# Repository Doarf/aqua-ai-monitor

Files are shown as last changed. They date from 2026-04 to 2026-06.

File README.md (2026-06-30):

# aqua-ai-monitor

<div align="center">

aqua-ai-monitor logo

**Automated monitoring system for aquaculture basins**  
*IoT · Isolation Forest AI · MJPEG Video · Node.js · Flask · Chart.js*













</div>

---

## About the project

**aqua-ai-monitor** is a fully autonomous embedded platform for real-time aquaculture basin monitoring. It combines physicochemical sensor acquisition, live underwater video streaming, automatic CSV logging, and an on-the-fly trainable **Isolation Forest** anomaly detection model — all accessible from a web dashboard, with optional remote access via ngrok.

### The problem

Aquaculture basins require constant monitoring. A pH shift, rising turbidity or abnormal water conditions can cause significant losses within hours. Manual monitoring is expensive, discontinuous and reactive — the need is to be **proactive**.

### The solution

| Need | Solution |
|---|---|
| Continuous acquisition | ESP32 reads 5 sensors every 2 s |
| Wi-Fi transmission | HTTP/JSON POST to Node.js server |
| Data history | Automatic CSV logging on PC |
| Anomaly detection | Isolation Forest (Python/Flask microservice) |
| Real-time visualization | Web dashboard with live charts (Chart.js) |
| Live video | ESP32-CAM + OV2640 → MJPEG stream |
| Remote access | ngrok HTTPS tunnel |

---

## Architecture

```
Physical sensors          OV2640 camera
      │                        │
      ▼ OneWire/ADC/I²C        ▼ MIPI CSI
  ESP32 Aqua              ESP32-CAM
      │                        │
      └──── Wi-Fi HTTP ─────────┘
                  │
                  ▼
        PC — Node.js (:3000) ◄──► Flask AI (:5001)
                  │                    │
                  │ ◄── /predict ───────┘
                  │
            data_aqua.csv  (auto-logged)
                  │
                  ▼
          Web Dashboard (:3000)
                  │
                  ▼ (optional)
          ngrok HTTPS tunnel
```

---

## Hardware components

| Component | Reference | Interface | Measured parameter |
|---|---|---|---|
| Main microcontroller | ESP32-WROOM-32 | Wi-Fi, GPIO | Acquisition & transmission |
| Camera microcontroller | ESP32-CAM | Wi-Fi, MIPI CSI | Underwater video |
| Water temperature | DS18B20 | OneWire (GPIO 4) | Water temp (°C) |
| Air temp & humidity | DHT22 | Single-wire (GPIO 15) | Air temp (°C), humidity (%) |
| pH sensor | PH-4502C | ADC (GPIO 34) | pH (0–14) |
| Turbidity sensor | Keyestudio V1.0 | ADC (GPIO 35) | Turbidity (NTU) |
| Camera | OV2640 | MIPI CSI | JPEG VGA video |
| OLED display | SSD1306 128×64 | I²C (GPIO 21/22) | Local readout |

---

## Software stack

| Layer | Technology | Role |
|---|---|---|
| Firmware | C++ / PlatformIO | Sensor reading, HTTP send |
| Server | Node.js / Express | Data relay, CSV logging, MJPEG proxy |
| AI service | Python / Flask | Isolation Forest training & inference |
| Dashboard | HTML/JS + Chart.js | Real-time charts, alerts, CSV upload |
| Remote access | ngrok | HTTPS tunnel |

---

## AI — Anomaly detection

The AI module uses an **Isolation Forest** model, trained on normal basin data collected by the system itself.

- **Unsupervised** — no labelled data required
- **Inputs** — pH and turbidity (NTU)
- **Double logic** — business rule thresholds + statistical IF score
- **Score** — normalized 0 (normal) → 1 (highly anomalous)
- **Trainable on the fly** — upload a CSV from the dashboard, click *Train*

```python
model = IsolationForest(n_estimators=200, contamination=0.05, random_state=42)
```

---

## Getting started

### Prerequisites

- Node.js ≥ 18
- Python ≥ 3.11
- PlatformIO
- ngrok (optional, for remote access)

### Launch the server & AI service

```bash
# Terminal 1 — Python AI microservice
cd esp32_cam_stream
pip install flask flask-cors scikit-learn pandas numpy joblib
python ai_service.py          # → http://localhost:5001

# Terminal 2 — Node.js server
cd esp32_cam_stream
npm install
node server.js                # → http://localhost:3000

# Terminal 3 — Remote access (optional)
ngrok http 3000
```

### Flash the ESP32 firmware

```bash
cd esp32_code/esp32_aqua
# Copy src/config_secret.h.example → src/config_secret.h
# Fill in your WIFI_SSID, WIFI_PASSWORD, SERVER_URL
pio run --target upload
pio device monitor --baud 115200
```

### Flash the ESP32-CAM

```bash
cd esp32_cam
# Copy src/config_secret.h.example → src/config_secret.h
# Fill in your WIFI_SSID and WIFI_PASSWORD
pio run --target upload
```

### Train the AI model

1. Let the system run for ~30 min under normal conditions
2. Open `http://localhost:3000`
3. Click **Download CSV** to get `data_aqua.csv`
4. Drag & drop the CSV into the AI panel → click **Train**
5. Model is active in under 1 second

---

## Repository structure

```
aqua-ai-monitor/
├── esp32_code/
│   └── esp32_aqua/              # Sensor firmware (PlatformIO)
│       └── src/
│           ├── main.cpp
│           ├── config.h
│           ├── config_secret.h.example
│           ├── ph_sensor.cpp/h
│           ├── turbidity_sensor.cpp/h
│           ├── ds18b20_sensor.cpp/h
│           ├── dht_sensor.cpp/h
│           ├── screen_oled.cpp/h
│           └── http_sender.cpp/h
├── esp32_cam/                   # Camera firmware (PlatformIO)
│   └── src/
│       ├── main.cpp
│       ├── camera.cpp/h
│       ├── streamer.cpp/h
│       ├── config.h
│       └── config_secret.h.example
├── esp32_cam_stream/            # Server + AI + Dashboard
│   ├── server.js                # Node.js/Express server
│   ├── ai_service.py            # Flask AI microservice
│   └── public/
│       └── index.html           # Web dashboard
├── SEBB_aqua/
│   └── carte_aqua/              # KiCad PCB project + Gerbers
├── docs/
│   └── banner.svg
├── rapport_aqua_ai_monitor.tex
└── rapport_aqua_ai_monitor.pdf
```

---

<div align="center">
  <sub>SPI Project · aqua-ai-monitor · IoT & AI for aquaculture</sub>
</div>

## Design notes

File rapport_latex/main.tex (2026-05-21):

% ============================================================
%  RAPPORT DE PROJET — aqua-ai-monitor
%  Plateforme Intelligente de Suivi en Aquaculture
%  CESI Nanterre — Programme FISA — SPI
% ============================================================
\documentclass[12pt,a4paper]{report}

% ── Encodage & langue ────────────────────────────────────────
\usepackage[utf8]{inputenc}
\usepackage[T1]{fontenc}
\usepackage[french]{babel}

% ── Mise en page ─────────────────────────────────────────────
\usepackage[top=2.5cm,bottom=2.5cm,left=2.8cm,right=2.8cm]{geometry}
\usepackage{setspace}
\onehalfspacing

% ── Typographie ──────────────────────────────────────────────
\usepackage{courier}
\usepackage[protrusion=false,expansion=false]{microtype}
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
\usepackage{fancyhdr}
\setlength{\headheight}{13.6pt}
\pagestyle{fancy}
\fancyhf{}
\fancyhead[L]{\small\textcolor{secondary}{aqua-ai-monitor}}
\fancyhead[R]{\small\textcolor{secondary}{\leftmark}}
\fancyfoot[C]{\small\textcolor{secondary}{\thepage}}
\renewcommand{\headrulewidth}{0.4pt}
\renewcommand{\footrulewidth}{0pt}

% ── Titres de chapitres personnalisés ────────────────────────
\usepackage{titlesec}
\titleformat{\chapter}[display]
  {\normalfont\huge\bfseries\color{primary}}
  {\chaptertitlename\ \thechapter}{12pt}{\Huge}
\titlespacing*{\chapter}{0pt}{-20pt}{30pt}

\titleformat{\section}
  {\normalfont\Large\bfseries\color{primary}}{\thesection}{1em}{}
\titleformat{\subsection}
  {\normalfont\large\bfseries\color{secondary}}{\thesubsection}{1em}{}
\titleformat{\subsubsection}
  {\normalfont\normalsize\bfseries\color{secondary}}{\thesubsubsection}{1em}{}

% ── Tableaux ─────────────────────────────────────────────────
\usepackage{booktabs}
\makeatletter
\def\CT@arc@{\relax}
\makeatother
\usepackage{tabularx}
\usepackage{multirow}
\usepackage{array}
\usepackage{longtable}
\newcolumntype{L}[1]{>{\raggedright\arraybackslash}p{#1}}
\newcolumntype{C}[1]{>{\centering\arraybackslash}p{#1}}
\newcolumntype{R}[1]{>{\raggedleft\arraybackslash}p{#1}}

% ── Listes ───────────────────────────────────────────────────
\usepackage{enumitem}
\setlist[itemize]{noitemsep, topsep=4pt}
\setlist[enumerate]{noitemsep, topsep=4pt}

% ── Code source ──────────────────────────────────────────────
\usepackage{listings}
\usepackage{lstautogobble}

\lstdefinestyle{mystyle}{
  backgroundcolor=\color{codebg},
  basicstyle=\ttfamily\footnotesize,
  breakatwhitespace=false,
  breaklines=true,
  captionpos=b,
  commentstyle=\color{accent}\itshape,
  keywordstyle=\color{primary}\bfseries,
  stringstyle=\color{warning},
  numbers=left,
  numberstyle=\tiny\color{secondary},
  numbersep=8pt,
  showstringspaces=false,
  tabsize=2,
  frame=single,
  framesep=4pt,
  rulecolor=\color{secondary!30},
  autogobble=true,
  xleftmargin=14pt,
}
\lstset{style=mystyle}

\lstdefinelanguage{JavaScript}{
  keywords={const,let,var,function,return,if,else,try,catch,async,await,new,require,module,exports,true,false,null},
  morestring=[b]',
  morestring=[b]",
  morecomment=[l]{//},
  morecomment=[s]{/*}{*/},
  sensitive=true
}

\lstdefinelanguage{Python3}{
  keywords={def,class,return,if,elif,else,for,while,import,from,try,except,with,as,True,False,None,and,or,not,in,is,lambda,global},
  morestring=[b]',
  morestring=[b]",
  morecomment=[l]{\#},
  sensitive=true
}

% ── Boîtes d'information ─────────────────────────────────────
\usepackage{tcolorbox}
\tcbuselibrary{breakable,skins}

\newtcolorbox{infobox}[1][]{
  colback=primary!5, colframe=primary!60,
  fonttitle=\bfseries, title=#1,
  breakable, boxrule=0.5pt, arc=3pt
}

\newtcolorbox{warningbox}[1][]{
  colback=warning!8, colframe=warning!60,
  fonttitle=\bfseries, title=#1,
  breakable, boxrule=0.5pt, arc=3pt
}

\newtcolorbox{successbox}[1][]{
  colback=accent!8, colframe=accent!60,
  fonttitle=\bfseries, title=#1,
  breakable, boxrule=0.5pt, arc=3pt
}

% ── Liens hypertextes ────────────────────────────────────────
\usepackage[hidelinks,colorlinks=true,linkcolor=primary,urlcolor=primary,citecolor=primary]{hyperref}

% ── Divers ───────────────────────────────────────────────────
\usepackage{float}
\usepackage{caption}
\captionsetup{font=small,labelfont=bf,labelsep=period}
\usepackage{subcaption}
\usepackage{amsmath}
\usepackage{amssymb}
\usepackage{pifont}
\newcommand{\cmark}{\textcolor{accent}{\ding{51}}}
\newcommand{\xmark}{\textcolor{danger}{\ding{55}}}

% ── Commandes personnalisées ─────────────────────────────────
\newcommand{\code}[1]{\texttt{\small\colorbox{codebg}{#1}}}
\newcommand{\param}[2]{\code{#1} & \small #2 \\}

% ============================================================
%  DÉBUT DU DOCUMENT
% ============================================================
\begin{document}

% ── Page de titre ────────────────────────────────────────────
\begin{titlepage}
  \centering
  \vspace*{1cm}

  \begin{tikzpicture}
    \node[circle,fill=primary,minimum size=3cm] (logo) {
      \textcolor{white}{\fontsize{40}{40}\selectfont\textbf{A}}
    };
  \end{tikzpicture}

  \vspace{0.8cm}
  {\fontsize{28}{32}\selectfont\bfseries\color{primary} aqua-ai-monitor}

  \vspace{0.4cm}
  {\Large\color{secondary} Plateforme Intelligente de Suivi en Aquaculture}

  \vspace{0.8cm}
  \textcolor{secondary!60}{\rule{0.6\textwidth}{0.4pt}}

  \vspace{0.8cm}
  {\large Rapport de Projet --- Systèmes et Projets Industriels}

  \vspace{1cm}
  \begin{tabular}{ll}
    \textbf{Établissement} & CESI Nanterre \\[4pt]
    \textbf{Programme}     & FISA --- Ingénierie des Systèmes Embarqués \\[4pt]
    \textbf{Promotion}     & 2024--2027 \\[4pt]
    \textbf{Encadrant}     & Kamel AIZI \\[4pt]
  \end{tabular}

  \vspace{1cm}
  \textcolor{secondary!60}{\rule{0.6\textwidth}{0.4pt}}

  \vspace{0.8cm}
  \textbf{Équipe projet}

  \vspace{0.4cm}
  \begin{tabular}{ll}
    DOGOTARU Arthur   & Chef de projet --- GUI, IA \\[4pt]
    LEGALL Maxence    & Capteurs, traitement de données \\[4pt]
    HAMMOUDA Nouhaila & PCB, schématique électronique \\[4pt]
  \end{tabular}

  \vspace{0.6cm}
  \textcolor{secondary!60}{\rule{0.6\textwidth}{0.4pt}}

  \vspace{0.4cm}
  {\small\color{secondary} Code source disponible sur GitHub :}\\[4pt]
  \href{https://github.com/Doarf/aqua_ai_monitor}{%
    \texttt{\color{primary}https://github.com/Doarf/aqua\_ai\_monitor}}

  \vfill
  {\color{secondary}\today}
\end{titlepage}

% ── Résumé ──────────────────────────────────────────────────
\chapter*{Résumé}
\addcontentsline{toc}{chapter}{Résumé}
\thispagestyle{fancy}

Le secteur de l'aquaculture est confronté à des défis croissants en matière de surveillance continue
des conditions d'élevage. Les variations de paramètres physicochimiques tels que le pH ou la turbidité
de l'eau peuvent provoquer des pertes importantes en quelques heures, sans que l'opérateur soit
nécessairement présent pour les détecter.

Le projet \textbf{aqua-ai-monitor} propose une réponse à cette problématique en développant une
plateforme embarquée autonome, combinant acquisition de données IoT, traitement temps réel et
intelligence artificielle. Le système repose sur deux microcontrôleurs ESP32 --- l'un dédié à l'acquisition
sensorielle (température, pH, turbidité, humidité), l'autre à la capture vidéo par caméra OV2640 ---
qui transmettent leurs données par Wi-Fi à un serveur central.

Ce serveur, développé en Node.js, agrège les flux de données, les enregistre dans un fichier CSV,
et les transmet à un microservice Python hébergeant un modèle \textit{Isolation Forest} entraînable
à la volée. La détection d'anomalies repose sur une double logique : seuils métier configurables
et score d'anomalie statistique. Les résultats sont présentés via un tableau de bord web en temps réel,
incluant graphiques d'évolution temporelle, alertes colorées et module d'entraînement par upload CSV.
L'accès distant est assuré via un tunnel ngrok sans configuration réseau spécifique.

\vspace{0.5cm}
\textbf{Mots-clés :} ESP32, IoT, aquaculture, détection d'anomalies, Isolation Forest,
Node.js, Flask, Chart.js, KiCad, PlatformIO, ngrok.

\clearpage

% ── Table des matières ───────────────────────────────────────
\tableofcontents
\clearpage

% ── Liste des figures ────────────────────────────────────────
\listoffigures
\addcontentsline{toc}{chapter}{Liste des figures}
\clearpage

% ── Liste des tableaux ───────────────────────────────────────
\listoftables
\addcontentsline{toc}{chapter}{Liste des tableaux}
\clearpage

% ============================================================
%  CHAPITRE 1 — INTRODUCTION ET CONTEXTE
% ============================================================
\chapter{Introduction et contexte}

\section{Présentation du projet}

Le projet \textbf{aqua-ai-monitor} est un système de surveillance automatisée de bassins
aquacoles développé dans le cadre du projet de Systèmes et Projets Industriels (SPI) de
deuxième année FISA au CESI Nanterre. Il vise à concevoir une plateforme complète, de la
couche matérielle embarquée jusqu'à l'interface utilisateur et l'intelligence artificielle,
répondant à une problématique industrielle réelle.

L'équipe est composée de trois étudiants aux compétences complémentaires :
\begin{itemize}
  \item \textbf{Arthur Dogotaru} --- Chef de projet, responsable de l'interface graphique (GUI),
        du microservice d'intelligence artificielle et de l'intégration logicielle globale ;
  \item \textbf{Legall Maxence} --- Responsable de l'intégration des capteurs et du traitement
        des données embarquées ;
  \item \textbf{Hammouda Nouhaila} --- Responsable de la conception PCB et des schématiques
        électroniques sous KiCad.
\end{itemize}

\section{Problématique industrielle}

L'aquaculture représente une part croissante de la production mondiale de protéines animales.
Selon la FAO~\cite{fao_aquaculture}, elle couvre aujourd'hui plus de 50\,\% de la consommation
mondiale de poissons. La gestion des bassins d'élevage constitue cependant un défi opérationnel
majeur : les organismes aquatiques sont extrêmement sensibles aux variations de leur environnement.

\begin{warningbox}[Risques liés à la surveillance manuelle]
Un écart de pH de 0,5 unité peut entraîner un stress physiologique significatif chez les
poissons. Une turbidité excessive indique une prolifération bactérienne ou une contamination.
Sans surveillance continue, ces anomalies peuvent provoquer des pertes totales d'un élevage
en moins de 24 heures.
\end{warningbox}

La surveillance manuelle présente trois limitations fondamentales :
\begin{enumerate}
  \item \textbf{Discontinuité} : les relevés manuels sont typiquement effectués une à deux fois
        par jour, laissant de larges fenêtres de non-détection ;
  \item \textbf{Réactivité} : une intervention humaine est nécessaire pour interpréter les mesures
        et déclencher une alerte, introduisant un délai incompressible ;
  \item \textbf{Coût} : la mobilisation permanente de personnel qualifié représente une charge
        opérationnelle élevée pour les petites et moyennes exploitations aquacoles.
\end{enumerate}

\section{Objectifs du projet}

Le projet aqua-ai-monitor vise à répondre à ces trois limitations par un système autonome
capable de :

\begin{itemize}
  \item Collecter en continu les paramètres physicochimiques (pH, turbidité, températures,
        humidité) via des capteurs connectés à un microcontrôleur ESP32 ;
  \item Transmettre ces données par Wi-Fi à un serveur central via le protocole HTTP/JSON ;
  \item Enregistrer les données dans un fichier CSV pour constitution d'un historique ;
  \item Analyser les données à l'aide d'un modèle d'apprentissage automatique non supervisé
        (Isolation Forest) pour détecter les anomalies sans nécessiter de labellisation préalable ;
  \item Présenter les résultats en temps réel sur un tableau de bord web accessible depuis
        n'importe quel navigateur sur le réseau local ;
  \item Permettre un accès distant au tableau de bord via un tunnel sécurisé ngrok,
        sans configuration réseau spécifique ;
  \item Capturer un flux vidéo sous-marin pour l'observation comportementale des poissons.
\end{itemize}

\section{Structure du rapport}

Ce rapport est organisé en dix chapitres. Le \textbf{chapitre~2} présente l'état de l'art
des systèmes IoT de surveillance aquacole et des méthodes de détection d'anomalies. Le
\textbf{chapitre~3} décrit l'architecture générale du système et les choix technologiques.
Le \textbf{chapitre~4} présente le matériel électronique et la carte PCB. Le
\textbf{chapitre~5} détaille les firmwares ESP32. Le \textbf{chapitre~6} présente le serveur
Node.js et l'infrastructure logicielle. Le \textbf{chapitre~7} développe le module
d'intelligence artificielle. Le \textbf{chapitre~8} présente le tableau de bord web. Le
\textbf{chapitre~9} présente les résultats et la validation du système. Le
\textbf{chapitre~10} conclut et ouvre sur les perspectives.

% ============================================================
%  CHAPITRE 2 — ÉTAT DE L'ART
% ============================================================
\chapter{État de l'art}
\label{chap:etat_art}

\section{Surveillance IoT de la qualité de l'eau en aquaculture}

La surveillance continue des paramètres physicochimiques d'un bassin aquacole
par des systèmes embarqués connectés est un axe de recherche actif depuis le milieu
des années 2010. Les travaux récents convergent vers une architecture commune :
des microcontrôleurs à faible consommation équipés de capteurs analogiques ou numériques,
transmettant leurs données via Wi-Fi ou LoRaWAN vers une plateforme de visualisation
et d'analyse.

\subsection{Systèmes ESP32 multi-capteurs pour l'aquaculture}

L'article de référence dans ce domaine est celui de Lin \textit{et al.}
\cite{lin2021aqua}, qui propose un système multi-capteurs intégrant température, pH,
oxygène dissous (DO) et conductivité électrique (EC) sur un module ESP32 Wi-Fi.
Les données sont transmises vers la plateforme ThingSpeak et visualisées via une
application mobile. Les auteurs rapportent une erreur absolue moyenne de
$0{,}0331$~°C sur la température après calibration, validant la pertinence de
l'ESP32 pour ce type d'application. Cette architecture est directement comparable
à celle d'\textbf{aqua-ai-monitor}, avec deux différences principales : notre
système ajoute un capteur de turbidité (NTU) et un module de détection d'anomalies
par apprentissage automatique, absents du travail de Lin \textit{et al.}

\subsection{Capteurs bas coût pour la surveillance IoT de l'eau}

Une revue systématique publiée dans \textit{Sensors} par de~Camargo \textit{et al.}
\cite{camargo2023lowcost} analyse 78~articles portant sur des capteurs bas coût
intégrés à des systèmes IoT de surveillance de la qualité de l'eau.
Les auteurs identifient le pH et la turbidité comme les paramètres les plus
fréquemment mesurés mais aussi les plus sensibles aux dérives de calibration.
Ils soulignent que les capteurs électrochimiques de pH présentent une dérive
temporelle non négligeable et nécessitent une recalibration régulière sur deux
points de référence --- constat que corrobore notre expérience avec le module
PH-4502C (cf.~section~\ref{sec:ph} et tableau~\ref{tab:validation}).
Cette revue justifie notre choix d'intégrer un \code{PH\_OFFSET} ajustable dans
\code{config.h} plutôt qu'une formule fixe.

\subsection{Limites de la surveillance par seuils fixes}

Les travaux de El-Shafeiy \textit{et al.} \cite{elshafeiy2023anomaly} montrent
que la simple vérification de seuils fixes est insuffisante pour détecter les
anomalies dans des séries temporelles de capteurs eau : les auteurs testent
plusieurs approches de détection sur des flux multi-capteurs et concluent que
les méthodes d'apprentissage non supervisé détectent des dégradations progressives
que les seuils manquent systématiquement. Cette observation motive directement
le couplage seuils métier + Isolation Forest retenu dans aqua-ai-monitor.

\section{Détection d'anomalies par apprentissage automatique non supervisé}

\subsection{Isolation Forest appliqué aux réseaux de capteurs IoT}

La détection d'anomalies dans les flux de capteurs IoT par Isolation Forest a été
étudiée dans plusieurs contextes récents. Zhuang \textit{et al.}
\cite{zhuang2023bsiforest} proposent BS-iForest, une variante améliorée de
l'algorithme original de Liu \textit{et al.} \cite{liu2008isolation}, appliquée
aux réseaux de capteurs sans fil. Les auteurs identifient deux limites de
l'Isolation Forest classique : une forte composante aléatoire entre deux
entraînements successifs sur le même jeu de données, et des performances dégradées
sur les données de faible densité. Pour notre application, la faible dimensionnalité
du problème (2~variables : pH et NTU) atténue ce second problème, et la graine
aléatoire fixée (\code{random\_state=42}) assure la reproductibilité de
l'entraînement.

\subsection{Comparaison avec les approches alternatives}

Les autoencodeurs (deep learning) sont régulièrement proposés dans la littérature
\cite{elshafeiy2023anomaly} mais leurs exigences en données d'entraînement
(plusieurs milliers de points) et en ressources de calcul les rendent inadaptés
à un déploiement sur PC local avec une phase de démarrage de quelques dizaines de
minutes. L'Isolation Forest, de complexité linéaire en $O(n \log n)$, peut
s'entraîner en moins d'une seconde sur 100~points, ce qui correspond exactement
à la contrainte opérationnelle du projet. Une comparaison détaillée des algorithmes
est présentée au tableau~\ref{tab:algos} du chapitre~\ref{chap:ia}.

\section{Outils de développement pour systèmes IoT embarqués}

Les systèmes IoT embarqués modernes s'appuient sur des environnements de
développement spécialisés. PlatformIO~\cite{platformio}, associé à l'éditeur
VS Code, s'est imposé comme la référence pour le développement sur
microcontrôleurs ESP32 : il unifie la gestion des bibliothèques, la compilation
et le flashage dans un seul outil, là où l'IDE Arduino classique montrait ses
limites sur des projets multi-fichiers. Lin \textit{et al.}~\cite{lin2021aqua}
utilisent également ce type d'environnement intégré pour leur système
multi-capteurs aquacole.

Côté serveur, Node.js s'est largement imposé pour les applications IoT temps
réel grâce à son modèle événementiel non bloquant, particulièrement adapté à la
gestion de nombreuses connexions simultanées à faible latence. La revue de
de~Camargo \textit{et al.}~\cite{camargo2023lowcost} recense Node.js parmi les
plateformes serveur les plus utilisées dans les architectures IoT de surveillance
environnementale.

Pour le prototypage mécanique, les imprimantes 3D de type \textbf{Bambu Lab}
permettent la fabrication rapide de boîtiers sur mesure adaptés aux contraintes
environnementales (humidité, câblage, fixation). Cette approche réduit le temps
entre prototype logiciel et déploiement physique, tendance recensée dans la
littérature IoT récente.

Enfin, l'accès distant aux dashboards IoT sans infrastructure réseau dédiée
est rendu possible par des outils de tunneling comme \textbf{ngrok}, qui créent
un tunnel HTTPS sécurisé entre un serveur local et internet. Cette approche est
particulièrement adaptée aux petites exploitations ne disposant pas d'adresse IP
fixe ni de configuration réseau avancée.

\begin{figure}[H]
  \centering
  \begin{subfigure}[b]{0.14\textwidth}
    \centering
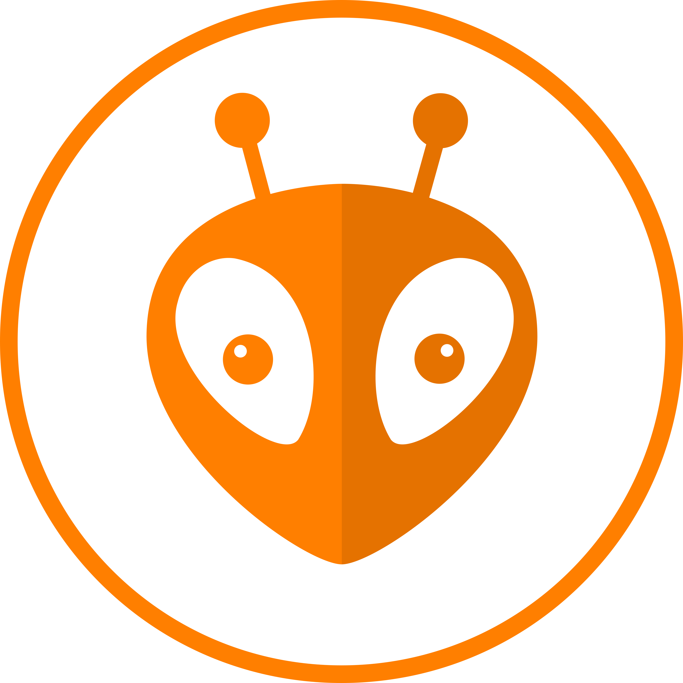
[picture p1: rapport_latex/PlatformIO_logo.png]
    
    \caption{PlatformIO}
  \end{subfigure}
  \hspace{0.5cm}
  \begin{subfigure}[b]{0.14\textwidth}
    \centering
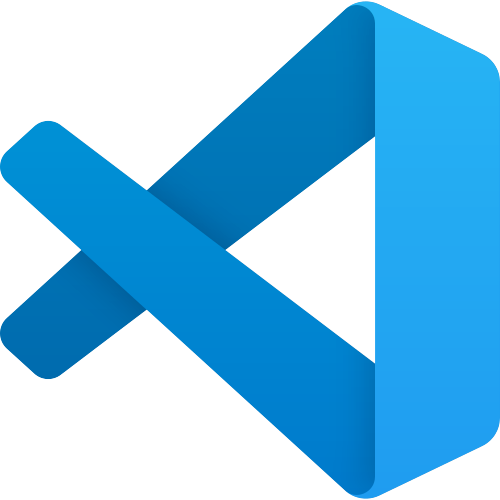
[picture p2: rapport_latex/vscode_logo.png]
    
    \caption{VS Code}
  \end{subfigure}
  \hspace{0.5cm}
  \begin{subfigure}[b]{0.20\textwidth}
    \centering
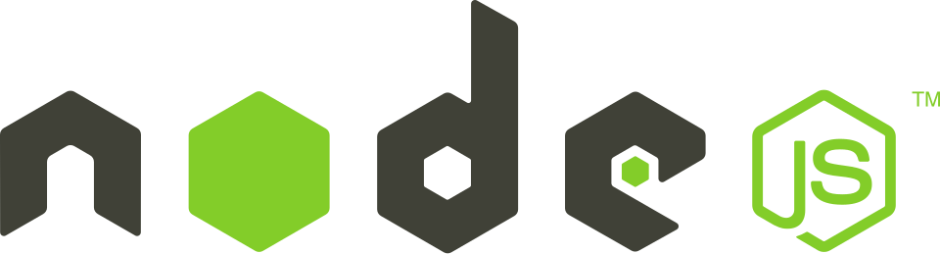
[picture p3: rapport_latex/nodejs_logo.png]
    
    \caption{Node.js}
  \end{subfigure}
  \hspace{0.5cm}
  \begin{subfigure}[b]{0.16\textwidth}
    \centering
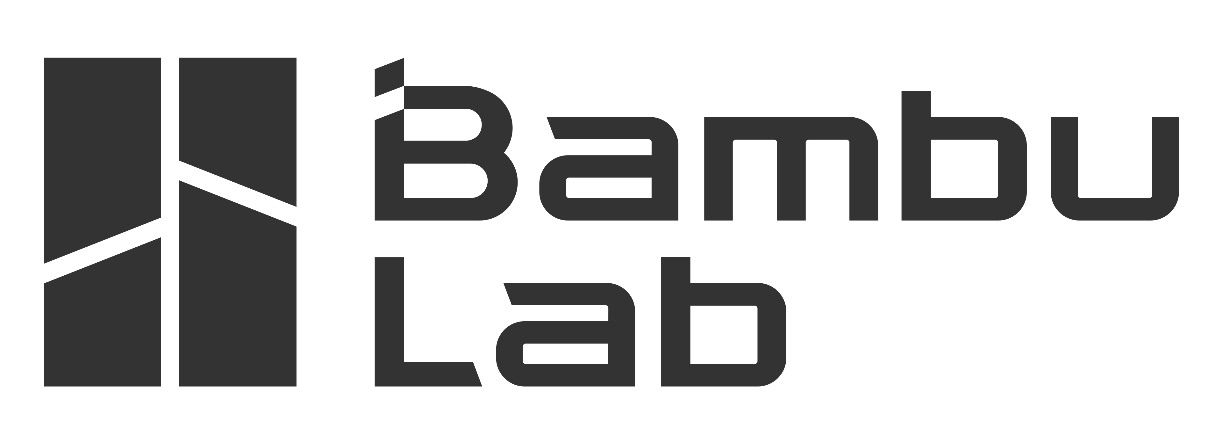
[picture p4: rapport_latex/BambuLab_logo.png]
    
    \caption{Bambu Lab}
  \end{subfigure}
  \hspace{0.5cm}
  \begin{subfigure}[b]{0.16\textwidth}
    \centering
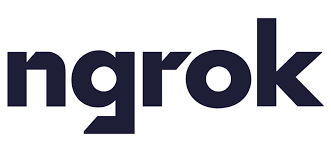
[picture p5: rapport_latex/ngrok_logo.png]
    
    \caption{ngrok}
  \end{subfigure}
  \caption{Outils logiciels et matériels de référence pour le développement IoT embarqué}
  \label{fig:logos_outils}
\end{figure}

\section{Positionnement du projet aqua-ai-monitor}

\begin{table}[H]
\centering
\caption{Positionnement d'aqua-ai-monitor par rapport aux travaux de l'état de l'art}
\label{tab:etat_art}
\begin{tabularx}{\textwidth}{@{}L{4cm}C{2cm}C{2cm}C{2.5cm}C{2.5cm}@{}}
\toprule
\textbf{Système} & \textbf{ESP32} & \textbf{Turbidité} & \textbf{Détection IA} & \textbf{Flux vidéo} \\
\midrule
Lin \textit{et al.}~\cite{lin2021aqua}                & \cmark & \xmark & \xmark        & \xmark \\
El-Shafeiy \textit{et al.}~\cite{elshafeiy2023anomaly} & \xmark & \cmark & \cmark (deep) & \xmark \\
Zhuang \textit{et al.}~\cite{zhuang2023bsiforest}     & \xmark & \xmark & \cmark (IF)   & \xmark \\
\textbf{aqua-ai-monitor}                              & \cmark & \cmark & \cmark (IF)   & \cmark \\
\bottomrule
\end{tabularx}
\end{table}

Le tableau~\ref{tab:etat_art} montre qu'aucun des travaux identifiés ne combine
simultanément une acquisition multi-capteurs sur ESP32, la mesure de turbidité,
la détection d'anomalies par Isolation Forest entraînable à la volée, et un flux
vidéo sous-marin. \textbf{aqua-ai-monitor} se positionne donc comme une intégration
originale de composants validés séparément dans la littérature, adaptée aux
contraintes opérationnelles et économiques des petites et moyennes exploitations
aquacoles.

% ============================================================
%  CHAPITRE 3 — ARCHITECTURE GÉNÉRALE
% ============================================================
\chapter{Architecture générale du système}

\section{Vue d'ensemble}

Le système aqua-ai-monitor est structuré en trois couches fonctionnelles distinctes,
conformément au modèle IoT classique :

\begin{itemize}
  \item \textbf{Couche perception} : deux microcontrôleurs ESP32 assurent l'acquisition
        des données physicochimiques (température, pH, turbidité, humidité) et la capture
        vidéo sous-marine via la caméra OV2640 ;
  \item \textbf{Couche réseau et traitement} : un serveur Node.js reçoit les données par
        Wi-Fi en HTTP/JSON, les enregistre en CSV, et les transmet à un microservice
        Python Flask hébergeant le modèle de détection d'anomalies Isolation Forest ;
  \item \textbf{Couche application} : un tableau de bord web (Chart.js) présente les
        mesures en temps réel, les alertes et le flux vidéo MJPEG, accessible localement
        ou à distance via un tunnel ngrok.
\end{itemize}

Ces trois couches sont illustrées dans la figure~\ref{fig:sch_fonctionnement}.

\begin{figure}[H]
  \centering
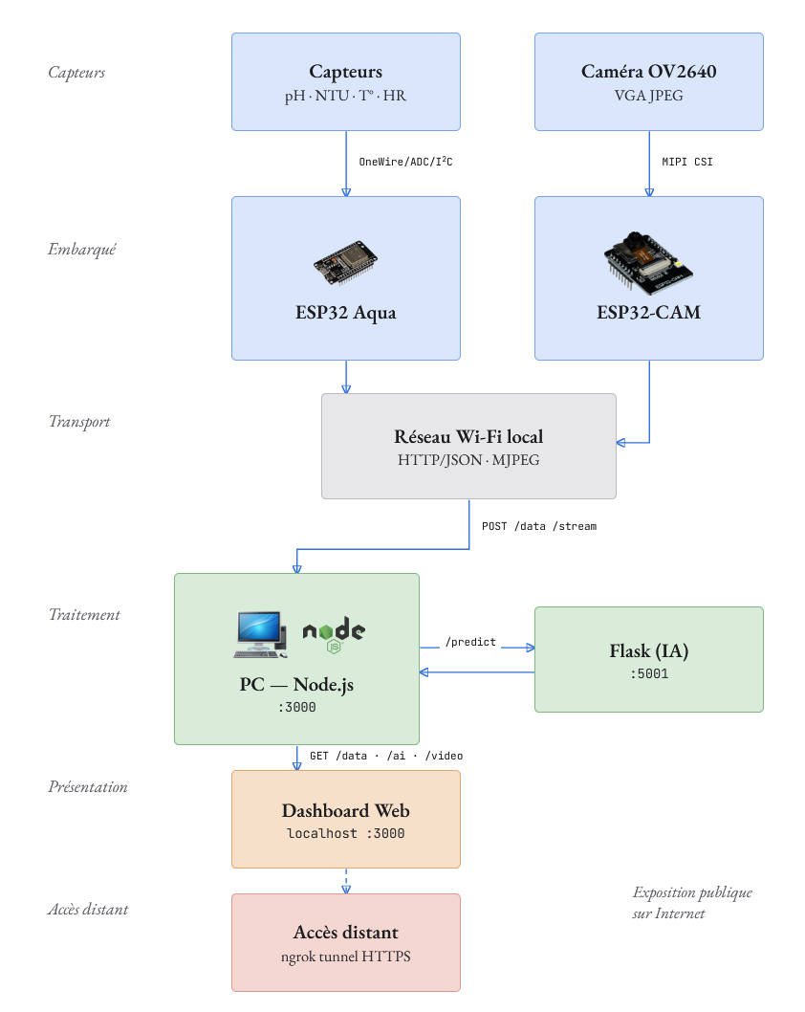
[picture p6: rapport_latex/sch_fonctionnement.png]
  
  \caption{Schéma de l'architecture du système aqua-ai-monitor}
  \label{fig:sch_fonctionnement}
\end{figure}

\section{Flux de données}

Le flux de données suit le chemin suivant :

\begin{center}
\small
\code{Capteurs} $\longrightarrow$ \code{ESP32 Aqua} $\longrightarrow$ \code{HTTP POST /data} $\longrightarrow$
\code{Node.js} $\longrightarrow$ \code{POST /predict (Flask)} $\longrightarrow$ \code{Dashboard}
\end{center}

En parallèle, le flux vidéo emprunte :

\begin{center}
\small
\code{OV2640} $\longrightarrow$ \code{ESP32-CAM} $\longrightarrow$ \code{HTTP POST /stream (chunks)} $\longrightarrow$
\code{Node.js} $\longrightarrow$ \code{GET /video (MJPEG)} $\longrightarrow$ \code{Dashboard}
\end{center}

Pour l'accès distant, un tunnel optionnel est ajouté en sortie du serveur :

\begin{center}
\small
\code{Node.js :3000} $\longrightarrow$ \code{ngrok tunnel} $\longrightarrow$
\code{https://xxxx.ngrok-free.app} $\longrightarrow$ \code{Navigateur distant}
\end{center}

\section{Choix technologiques}

\begin{table}[H]
\centering
\caption{Tableau des choix technologiques}
\label{tab:techno}
\begin{tabularx}{\textwidth}{@{}L{3cm}L{3.5cm}L{7cm}@{}}
\toprule
\textbf{Composant} & \textbf{Technologie} & \textbf{Justification} \\
\midrule
Microcontrôleur & ESP32-WROOM-32 & Wi-Fi intégré, ADC 12 bits, bibliothèques Arduino riches, faible coût~\cite{lin2021aqua} \\
\addlinespace
Firmware & C++/PlatformIO & Abstraction Arduino, gestion de projets multi-fichiers, OTA possible \\
\addlinespace
Communication & HTTP/JSON & Simplicité d'intégration, pas de broker requis, compatible LAN \\
\addlinespace
Serveur & Node.js/Express & Asynchrone natif, adapté aux flux temps réel, npm riche \\
\addlinespace
IA & Python/Flask & Écosystème scikit-learn mature, Flask léger pour microservice \\
\addlinespace
Modèle IA & Isolation Forest & Non supervisé, efficace sur peu de variables, interprétable~\cite{liu2008isolation} \\
\addlinespace
Dashboard & HTML/JS vanilla + Chart.js & Pas de dépendance framework, déploiement immédiat \\
\addlinespace
Accès distant & ngrok & Tunnel HTTPS local $\rightarrow$ internet, sans configuration réseau \\
\addlinespace
PCB & KiCad 10 & Open-source, export Gerber standard, bibliothèques communautaires \\
\bottomrule
\end{tabularx}
\end{table}

\section{Protocole de communication ESP32 → Serveur}

L'ESP32 fonctionne en mode \textbf{STATION} (STA) : il se connecte au réseau
Wi-Fi local existant via le routeur, exactement comme un ordinateur ou un
smartphone classique. Ce mode est illustré en figure~\ref{fig:esp32_wifi} ---
l'ESP32 (STATION) envoie ses requêtes HTTP au routeur (ACCESS POINT), qui les
route vers le PC hébergeant le serveur Node.js sur le même réseau local.
Ce choix permet à l'ESP32 et au serveur de partager la même plage d'adresses
IP, rendant les requêtes HTTP POST directement adressables via l'IP fixe
configurée dans \code{config.h}.

\begin{figure}[H]
  \centering
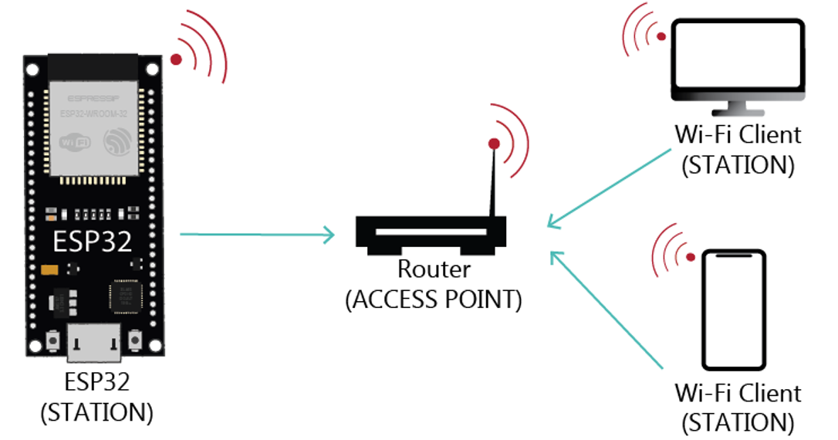
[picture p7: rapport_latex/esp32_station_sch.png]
  
  \caption{Mode STATION de l'ESP32 --- connexion au réseau Wi-Fi local via le routeur}
  \label{fig:esp32_wifi}
\end{figure}

L'ESP32 aqua envoie une requête HTTP POST toutes les 2 secondes vers l'endpoint
\code{/data} du serveur. Le corps de la requête est un objet JSON :

\begin{lstlisting}[language=JavaScript,caption={Structure JSON envoyée par l'ESP32}]
{
  "temperature": 20.4,   // Temperature air (deg C) - DHT22
  "humidity":    60.2,   // Humidite relative (%) - DHT22
  "ph":           7.23,  // pH de l'eau - capteur PH-4502C
  "ntu":        542.0,   // Turbidite (NTU) - Keyestudio V1.0
  "waterTemp":   17.87   // Temperature eau (deg C) - DS18B20
}
\end{lstlisting}

L'ESP32-CAM envoie quant à lui un flux HTTP chunked en \code{Transfer-Encoding: chunked},
dans lequel chaque chunk correspond à une frame JPEG capturée par l'OV2640.

% ============================================================
%  CHAPITRE 4 — MATÉRIEL ET PCB
% ============================================================
\chapter{Matériel électronique et conception PCB}

\section{Composants utilisés}

\begin{table}[H]
\centering
\caption{Inventaire des composants matériels}
\label{tab:composants}
\begin{tabularx}{\textwidth}{@{}L{3.5cm}L{3cm}L{3cm}L{4cm}@{}}
\toprule
\textbf{Composant} & \textbf{Référence} & \textbf{Interface} & \textbf{Paramètre mesuré} \\
\midrule
Microcontrôleur principal & ESP32-WROOM-32 & Wi-Fi, GPIO & Coordination, transmission \\
Microcontrôleur caméra & ESP32-CAM & Wi-Fi, MIPI & Vidéo sous-marine \\
Capteur température eau & DS18B20 & OneWire (GPIO~4) & Température eau (°C) \\
Capteur temp./humidité & DHT22 & Single-wire (GPIO~15) & Temp. air (°C), humidité (\%) \\
Capteur pH & PH-4502C & ADC (GPIO~34) & pH (0--14) \\
Capteur turbidité & Keyestudio V1.0 & ADC (GPIO~35) & Turbidité (NTU) \\
Caméra & OV2640 & MIPI CSI & Image JPEG VGA \\
Écran OLED & SSD1306 128×64 & I²C (GPIO~21/22) & Affichage local \\
\bottomrule
\end{tabularx}
\end{table}

\section{Microcontrôleurs}

\subsection{ESP32-WROOM-32 --- microcontrôleur principal}

L'ESP32-WROOM-32 est le microcontrôleur central du système. Il assure l'acquisition
de tous les paramètres physicochimiques et la transmission Wi-Fi vers le serveur
Node.js. La figure~\ref{fig:esp32_pinout} présente son brochage complet (30 GPIO).
Les broches utilisées dans le projet sont : GPIO~34 (ADC1\_CH6) pour le capteur
pH, GPIO~35 (ADC1\_CH7) pour la turbidité --- toutes deux en entrée analogique
uniquement --- GPIO~4 pour le bus OneWire du DS18B20, GPIO~15 pour le DHT22, et
le bus I²C sur GPIO~21 (SDA) et GPIO~22 (SCL) pour l'écran OLED. Les broches
GPIO~6 à GPIO~11 sont réservées à la mémoire Flash interne et ne doivent pas
être utilisées.

\begin{figure}[H]
  \centering
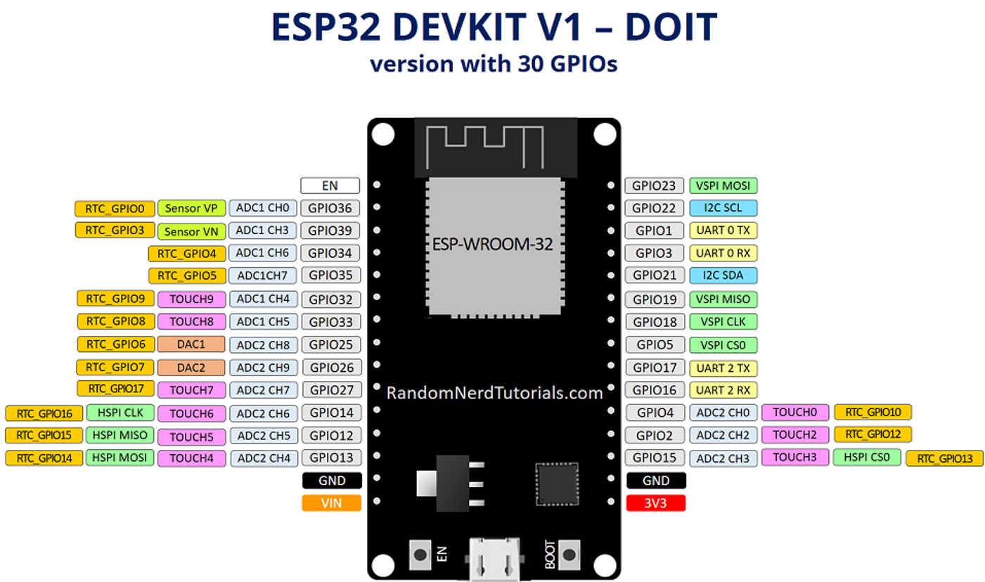
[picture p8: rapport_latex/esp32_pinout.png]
  
  \caption{Brochage de l'ESP32 DEVKIT V1 --- ESP-WROOM-32 (30 GPIO)}
  \label{fig:esp32_pinout}
\end{figure}

\subsection{ESP32-CAM --- microcontrôleur caméra}

L'ESP32-CAM est un module compact intégrant un microcontrôleur ESP32-S et un
connecteur MIPI CSI pour la caméra OV2640. Son brochage est présenté en
figure~\ref{fig:esp32_cam_pinout}. Les broches GPIO~12 à GPIO~15 et GPIO~2
sont monopolisées par le bus SDIO de la caméra (\code{HS2\_DATA},
\code{HS2\_CLK}, \code{HS2\_CMD}) et ne sont pas disponibles pour d'autres
usages. L'alimentation est 5~V sur la broche \code{5V}, le régulateur interne
fournissant le 3,3~V à l'ensemble du module. La broche \code{GPIO~0} contrôle
le mode de démarrage : reliée à GND lors du flashage, elle doit être libérée
pour l'exécution normale du firmware.

\begin{figure}[H]
  \centering
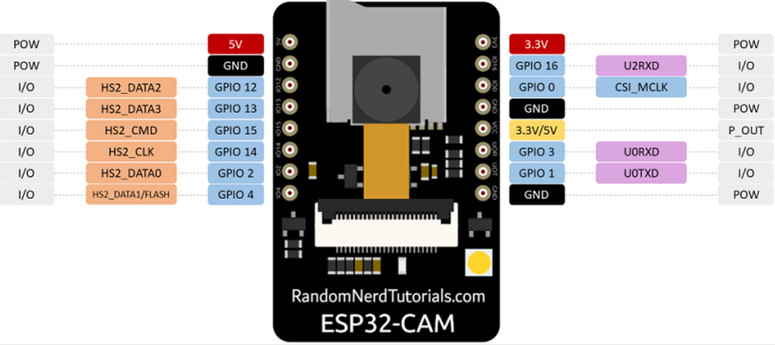
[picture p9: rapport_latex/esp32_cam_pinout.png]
  
  \caption{Brochage de l'ESP32-CAM}
  \label{fig:esp32_cam_pinout}
\end{figure}

\section{Capteur de pH --- PH-4502C}
\label{sec:ph}

\subsection{Principe de fonctionnement}

Le capteur PH-4502C est basé sur une électrode de verre combinée. La différence de potentiel
développée par l'électrode suit l'équation de Nernst~\cite{ph4502c} :

\begin{equation}
E = E_0 + \frac{RT}{nF} \ln[\text{H}^+] = E_0 - \frac{RT}{F} \cdot \text{pH}
\label{eq:nernst}
\end{equation}

où $R = 8{,}314$~J/(mol·K), $T$ la température en Kelvin, $F = 96485$~C/mol et $n = 1$.

\subsection{Implémentation sur ESP32}

L'ESP32 lit la tension en sortie du module via son ADC 12 bits (résolution 4095 niveaux,
plage 0--3{,}3~V après atténuation \code{ADC\_11db}). La conversion tension → pH est réalisée
par une droite affine étalonnée sur deux points de référence. Conformément aux
recommandations de de~Camargo \textit{et al.}~\cite{camargo2023lowcost}, un offset
ajustable est prévu pour la recalibration terrain :

\begin{equation}
\text{pH} = 9{,}18 + (0{,}781 - V) \times 8{,}5 + \text{offset}
\label{eq:ph_conv}
\end{equation}

Les points de calibration utilisés sont :
\begin{itemize}
  \item $V = 0{,}781$~V $\rightarrow$ pH~9,18 (solution tampon basique) ;
  \item $V = 1{,}388$~V $\rightarrow$ pH~4,00 (solution tampon acide).
\end{itemize}

\subsection{Filtrage numérique}

Pour réduire le bruit de conversion, chaque mesure de pH est obtenue par moyenne sur
$N = 10$ échantillons espacés de 10~ms :

\begin{lstlisting}[language=C++,caption={Filtrage par moyennage -- ph\_sensor.cpp}]
float PHSensor::read() {
  long sum = 0;
  for (int i = 0; i < PH_SAMPLES; i++) {
    sum += analogRead(PH_PIN);
    delay(10);
  }
  float raw     = sum / (float)PH_SAMPLES;
  float voltage = (raw / 4095.0f) * PH_VREF;
  return _voltageToPhValue(voltage);
}
\end{lstlisting}

\section{Capteur de turbidité --- Keyestudio V1.0}

Le capteur de turbidité fonctionne par mesure de la diffusion lumineuse (principe
néphélométrique). La tension de sortie est inversement proportionnelle à la turbidité :
une eau claire produit une tension élevée ($\approx$1,533~V), une eau très trouble une tension
proche de 0~V.

\begin{equation}
\text{NTU} = \left(1{,}533 - V\right) \times \frac{3000}{1{,}533}
\label{eq:ntu_conv}
\end{equation}

\begin{warningbox}[Limite du modèle linéaire]
La relation linéaire proposée est une approximation. Pour des mesures précises
au-delà de 500~NTU, une calibration multi-points avec des solutions étalons
certifiées (normes ISO~7027) est recommandée~\cite{camargo2023lowcost}.
\end{warningbox}

\section{Capteur DS18B20}

Le DS18B20 est un capteur de température numérique à protocole OneWire, étanche, utilisé
pour la mesure de température de l'eau. Sa résolution est configurable de 9 à 12 bits
(±0,5°C à ±0,0625°C)~\cite{ds18b20}. La bibliothèque \code{DallasTemperature} gère
l'intégralité du protocole OneWire, permettant un code applicatif simple :

\begin{lstlisting}[language=C++,caption={Lecture DS18B20 -- ds18b20\_sensor.cpp}]
float DS18B20Sensor::read() {
  _sensors.requestTemperatures();
  float temp = _sensors.getTempCByIndex(0);
  if (temp == DEVICE_DISCONNECTED_C) return -127.0f;
  return temp;
}
\end{lstlisting}

La valeur sentinel \code{-127.0f} permet de détecter une déconnexion physique du capteur
et de l'indiquer dans l'interface.

\section{Conception PCB --- KiCad 10}

\subsection{Objectifs de la carte}

La carte PCB \textit{carte\_aqua}, conçue par Hammouda Nouhaila sous KiCad~10, a pour
objectif de regrouper sur un circuit imprimé les connecteurs nécessaires à l'ensemble
des capteurs, l'alimentation et l'ESP32-WROOM-32 DevKit V1. Elle supprime le câblage
sur breadboard pour un déploiement fiable en environnement humide.

\subsection{Schématique électronique}

La figure~\ref{fig:sch_pcb} présente le schéma électronique complet de la carte
\textit{carte\_aqua}, réalisé sous KiCad~10~\cite{kicad}. On y retrouve les six connecteurs
(J1~à~J6) reliés aux capteurs DS18B20, DHT22, pH, turbidité, écran OLED et
alimentation Jack-DC, ainsi que la résistance de pull-up R1 sur la ligne OneWire
du DS18B20, et le microcontrôleur central U1 (DEVKIT\_V1\_ESP32-WROOM-32).

\begin{figure}[H]
  \centering
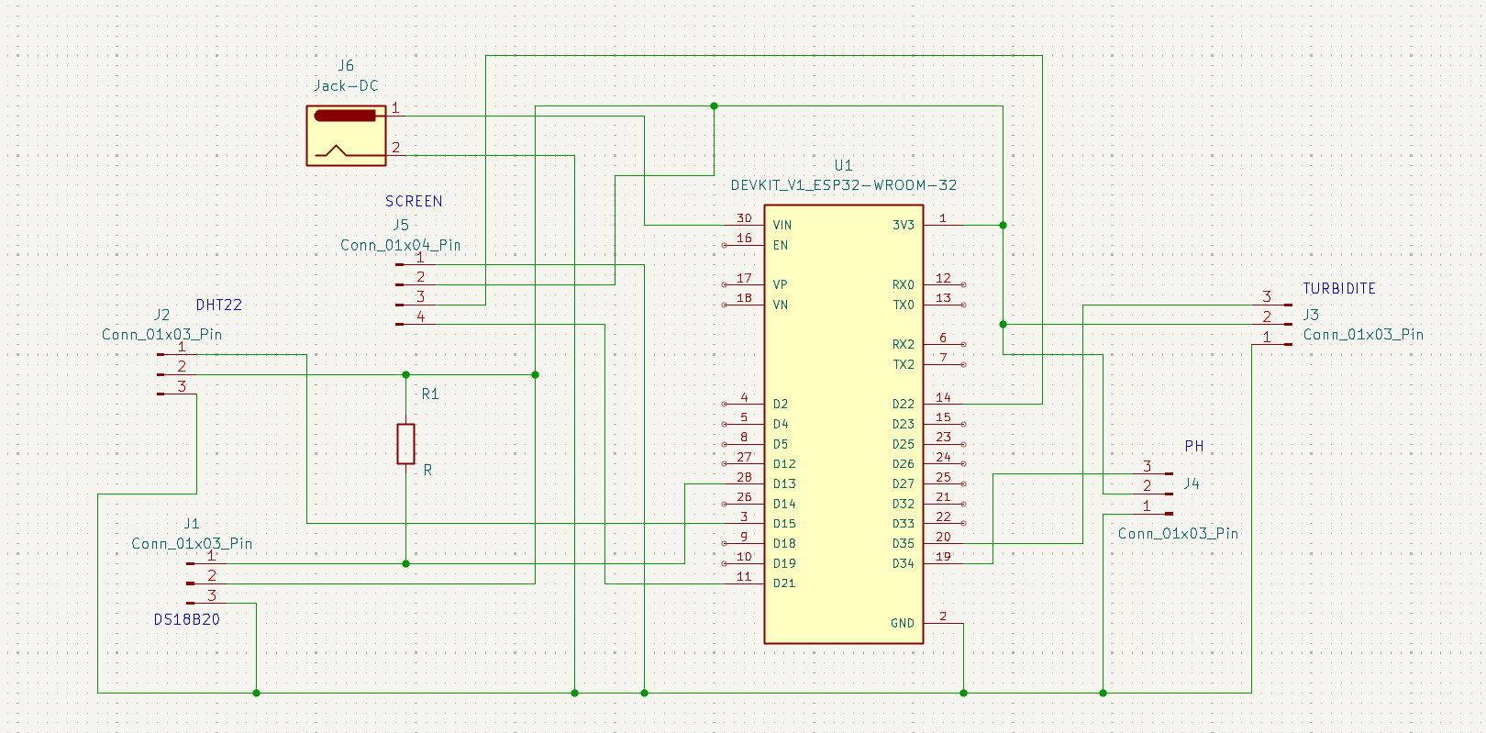
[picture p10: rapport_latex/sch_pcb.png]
  
  \caption{Schématique électronique de la carte aqua-ai-monitor (KiCad 10)}
  \label{fig:sch_pcb}
\end{figure}

\subsection{Routage PCB}

La figure~\ref{fig:routage_pcb} présente la vue de routage en couche F\_Cu
(rouge). Les pistes relient les headers de l'ESP32 DevKit aux connecteurs
périphériques disposés sur les bords gauche et droit de la carte. Les quatre
trous de fixation assurent le maintien mécanique du module. Les pistes
d'alimentation (5~V et GND) sont routées en priorité avec une largeur
supérieure aux pistes signal.

\begin{figure}[H]
  \centering
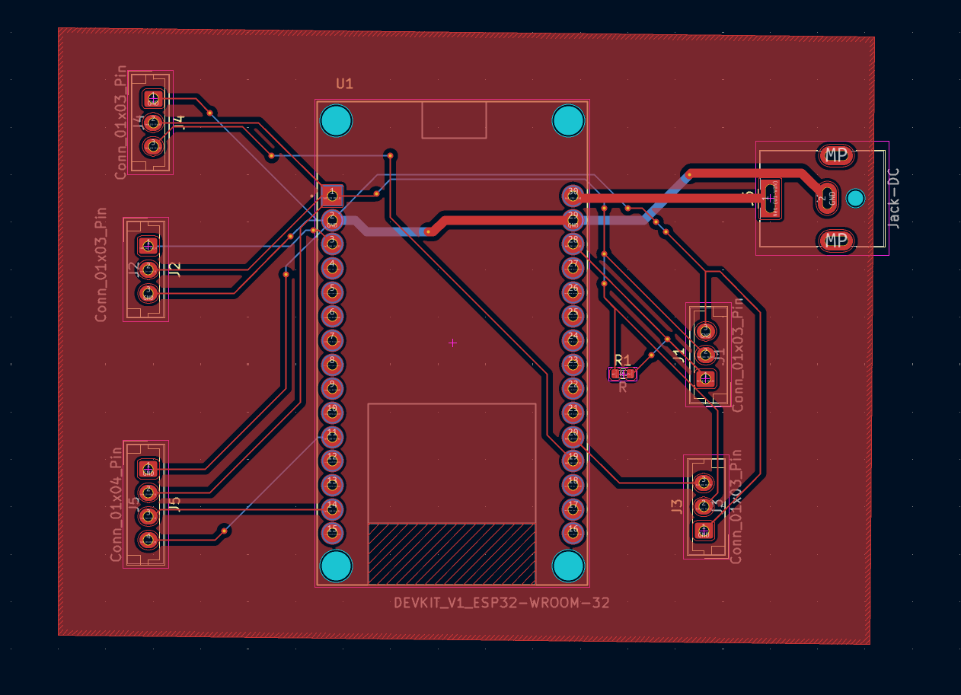
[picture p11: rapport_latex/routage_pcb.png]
  
  \caption{Vue de routage PCB --- couche F\_Cu (KiCad 10)}
  \label{fig:routage_pcb}
\end{figure}

\subsection{Visualisation 3D}

La figure~\ref{fig:3d_pcb} présente le rendu 3D de la carte généré par le
visualiseur intégré de KiCad~10. On distingue clairement l'empreinte du
module ESP32-WROOM-32 au centre (U1), les connecteurs JST-XH, la résistance
CMS R1, et le connecteur d'alimentation Jack-DC (J6).

\begin{figure}[H]
  \centering
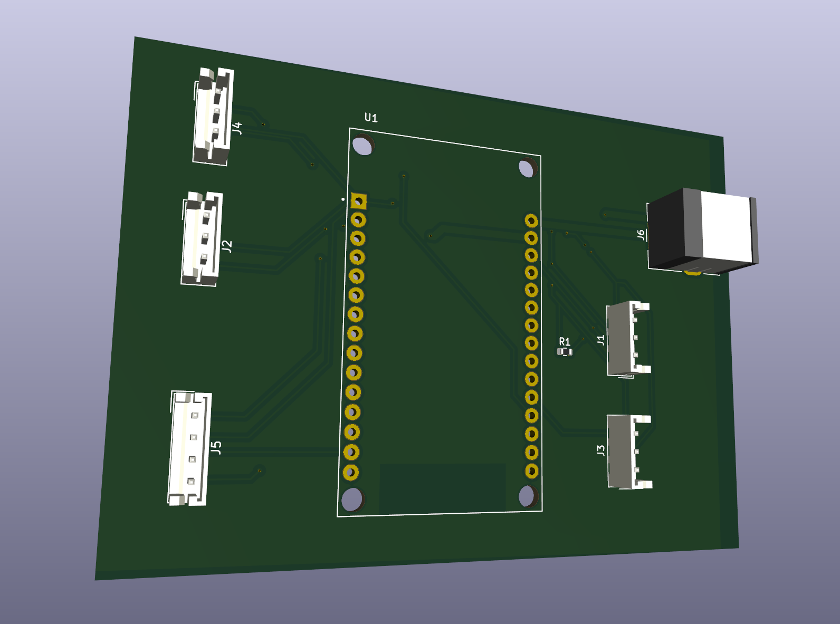
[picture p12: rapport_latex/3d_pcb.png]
  
  \caption{Rendu 3D de la carte aqua-ai-monitor (KiCad 10)}
  \label{fig:3d_pcb}
\end{figure}

\subsection{Caractéristiques techniques}

\begin{table}[H]
\centering
\caption{Caractéristiques de la carte PCB carte\_aqua}
\label{tab:pcb}
\begin{tabularx}{\textwidth}{@{}L{5cm}L{9cm}@{}}
\toprule
\textbf{Caractéristique} & \textbf{Valeur} \\
\midrule
Outil de conception & KiCad 10 \\
Nombre de couches & 2 (F\_Cu, B\_Cu) \\
Fichiers de sortie & Gerber (F/B\_Cu, F/B\_Mask, F/B\_Silk, Edge\_Cuts) \\
Alimentation & 5~V / 2~A (USB ou bloc secteur) \\
Microcontrôleur intégré & ESP32-WROOM-32 DevKit V1 (empreinte 3D incluse) \\
Connecteurs capteurs & JST-XH 2.54~mm (DS18B20, DHT22, pH, turbidité, OLED) \\
\bottomrule
\end{tabularx}
\end{table}

\subsection{Fichiers de fabrication}

Les fichiers Gerber exportés permettent une fabrication directe chez tout fabricant PCB
standard (JLCPCB, PCBWay, etc.). Les couches exportées comprennent :
\code{F\_Cu}, \code{B\_Cu}, \code{F\_Mask}, \code{B\_Mask}, \code{F\_Silkscreen},
\code{B\_Silkscreen} et \code{Edge\_Cuts}.

\section{Boîtier de protection --- Impression 3D}

Pour assurer la protection mécanique du prototype en environnement humide,
un boîtier sur mesure a été conçu et imprimé en 3D. L'impression a été
réalisée sur une imprimante \textbf{Bambu Lab}, reconnue pour sa précision
dimensionnelle et sa vitesse d'impression. Le matériau retenu est le PLA,
suffisant pour un usage en intérieur à proximité d'un bassin.

Le boîtier intègre les ouvertures nécessaires au passage des câbles capteurs,
au connecteur USB de programmation de l'ESP32, et à la ventilation passive
du module. Les figures~\ref{fig:pcb_irl} et~\ref{fig:pcb_irl_2} présentent
le prototype assemblé dans ce boîtier.

\begin{figure}[H]
  \centering
  
  \caption{Bambu Lab --- imprimante 3D utilisée pour la fabrication du boîtier}
  \label{fig:bambulab_logo}
\end{figure}

% ============================================================
%  CHAPITRE 5 — FIRMWARE ESP32
% ============================================================
\chapter{Firmware ESP32}

\section{Organisation du projet PlatformIO}

Le firmware est développé avec PlatformIO~\cite{platformio} sous VS Code
(cf.~figure~\ref{fig:logos_outils}), ciblant la plateforme \code{espressif32}
avec le framework Arduino~\cite{espressif_esp32}. L'organisation suit le
modèle orienté objet, avec une classe dédiée par capteur ou sous-système :

\begin{lstlisting}[caption={Structure du firmware esp32\_aqua}]
esp32_aqua/
  src/
    main.cpp             -- Boucle principale
    config.h             -- Constantes de configuration
    dht_sensor.cpp/h     -- Classe DHTSensor
    ds18b20_sensor.cpp/h -- Classe DS18B20Sensor
    ph_sensor.cpp/h      -- Classe PHSensor
    turbidity_sensor.cpp/h -- Classe TurbiditySensor
    screen_oled.cpp/h    -- Classe ScreenOLED
    http_sender.cpp/h    -- Classe HttpSender
  platformio.ini         -- Configuration build
\end{lstlisting}

\section{Boucle principale non-bloquante}

La boucle \code{loop()} est conçue sans aucun appel bloquant global. Chaque classe
expose une méthode \code{isReady()} qui retourne \code{true} lorsque l'intervalle
de lecture configuré est écoulé depuis la dernière mesure. Cette approche évite
l'utilisation de tâches FreeRTOS tout en maintenant une réactivité suffisante.

\begin{lstlisting}[language=C++,caption={Boucle principale non-bloquante -- main.cpp}]
void loop() {
  if (dhtSensor.isReady())       lastData      = dhtSensor.read();
  if (phSensor.isReady())        lastPh        = phSensor.read();
  if (turbSensor.isReady())      lastNtu       = turbSensor.read();
  if (waterTempSensor.isReady()) lastWaterTemp = waterTempSensor.read();

  if (lastData.valid) {
    screen.showData(lastData, lastPh, lastNtu, lastWaterTemp);
    if (sender.isReady())
      sender.send(lastData, lastPh, lastNtu, lastWaterTemp);
  } else {
    screen.showError("DHT22 KO");
  }
}
\end{lstlisting}

\section{Configuration centralisée}

Toutes les constantes de configuration (SSID, mot de passe Wi-Fi, adresse serveur,
broches GPIO, intervalles de lecture) sont regroupées dans \code{config.h} :

\begin{lstlisting}[language=C++,caption={Extrait de config.h}]
#define WIFI_SSID     "MonReseau"
#define WIFI_PASSWORD "MotDePasse"
#define SERVER_URL    "http://192.168.1.73:3000/data"
#define DHTPIN        15
#define PH_PIN        34
#define TURB_PIN      35
#define DS18B20_PIN   4
#define PH_OFFSET     1.00f
#define PH_READ_INTERVAL_MS   2000
#define TURB_READ_INTERVAL_MS 2000
\end{lstlisting}

\begin{warningbox}[Sécurité des credentials]
Les identifiants Wi-Fi sont actuellement stockés en clair dans \code{config.h}.
Pour un déploiement en production, il est recommandé d'utiliser le mécanisme
de provisionnement Wi-Fi d'Espressif (SmartConfig ou BLE provisioning) ou de
stocker les credentials dans la partition NVS de l'ESP32~\cite{espressif_esp32}.
\end{warningbox}

\section{Envoi HTTP}

La classe \code{HttpSender} utilise la bibliothèque \code{HTTPClient} d'Arduino pour
ESP32. Le corps de la requête est construit manuellement en JSON pour éviter la
dépendance à une bibliothèque JSON volumineuse :

\begin{lstlisting}[language=C++,caption={Construction et envoi du JSON -- http\_sender.cpp}]
void HttpSender::send(const SensorData& data,
                      float ph, float ntu, float waterTemp) {
  HTTPClient http;
  http.begin(SERVER_URL);
  http.addHeader("Content-Type", "application/json");

  String json = "{";
  json += "\"temperature\":" + String(data.temperature, 1) + ",";
  json += "\"humidity\":"    + String(data.humidity, 1)    + ",";
  json += "\"ph\":"          + String(ph, 2)               + ",";
  json += "\"ntu\":"         + String(ntu, 1)              + ",";
  json += "\"waterTemp\":"   + String(waterTemp, 2);
  json += "}";

  int code = http.POST(json);
  http.end();
}
\end{lstlisting}

\section{Affichage local --- écran OLED SSD1306}

L'écran OLED SSD1306 (128$\times$64 pixels, I²C) assure un retour visuel local
sans nécessiter d'ordinateur connecté. La classe \code{ScreenOLED} implémente
un affichage rotatif en \textbf{trois pages}, chacune affichée pendant 3 secondes :

\begin{enumerate}
  \item \textbf{Page Ambiance} : température air et humidité (DHT22) ;
  \item \textbf{Page Eau} : température eau (DS18B20) et pH (PH-4502C) ;
  \item \textbf{Page Turbidité} : valeur NTU (Keyestudio V1.0).
\end{enumerate}

Ce cycle permet de surveiller visuellement les cinq paramètres sans interaction,
utile lors des phases de calibration ou de débogage sur le terrain.

\subsection{Gestion des erreurs capteurs}

Le firmware détecte et signale les défaillances matérielles directement sur
l'écran via la méthode \code{showError()}. Le tableau~\ref{tab:oled_errors}
récapitule les messages d'erreur possibles et leurs causes.

\begin{table}[H]
\centering
\caption{Messages d'erreur affichés sur l'écran OLED}
\label{tab:oled_errors}
\begin{tabularx}{\textwidth}{@{}L{3cm}L{3.5cm}L{7cm}@{}}
\toprule
\textbf{Message} & \textbf{Capteur} & \textbf{Cause probable} \\
\midrule
\code{DHT22 KO} & DHT22 & Déconnexion physique ou broche GPIO~15 défectueuse \\
\addlinespace
\code{DS18B20 KO} & DS18B20 & Valeur sentinelle \code{-127.0f} --- capteur déconnecté du bus OneWire ou résistance pull-up 4,7~k$\Omega$ manquante \\
\addlinespace
\code{WiFi KO} & Module Wi-Fi & SSID ou mot de passe incorrect dans \code{config.h}, ou routeur hors portée \\
\addlinespace
\code{OLED KO} & SSD1306 & Adresse I²C incorrecte (attendu \code{0x3C}) --- signalé sur la console série \\
\bottomrule
\end{tabularx}
\end{table}

\begin{infobox}[Priorité d'affichage]
Le DHT22 est le seul capteur dont l'échec bloque le cycle d'affichage normal
(\code{SensorData.valid} est faux). Les autres capteurs affichent leur dernière
valeur valide même en cas de déconnexion temporaire --- la valeur \code{-127.0f}
du DS18B20 apparaîtra sur la page Eau comme \code{T:-127.0C}, signal visuel
d'une anomalie matérielle.
\end{infobox}

\section{Firmware ESP32-CAM}

\subsection{Initialisation de la caméra OV2640}

Le firmware de l'ESP32-CAM initialise la caméra avec la configuration suivante :

\begin{table}[H]
\centering
\caption{Paramètres de configuration de la caméra OV2640}
\label{tab:camera}
\begin{tabularx}{\textwidth}{@{}L{5cm}L{3cm}L{6cm}@{}}
\toprule
\textbf{Paramètre} & \textbf{Valeur} & \textbf{Commentaire} \\
\midrule
Format pixel & JPEG & Compression embarquée \\
Résolution & VGA (640×480) & Compromis qualité/débit \\
Qualité JPEG & 6 & 0 (max) -- 63 (min) \\
Nombre de buffers & 2 & Double buffering anti-tearing \\
Fréquence XCLK & 20~MHz & Fréquence standard OV2640 \\
\bottomrule
\end{tabularx}
\end{table}

\subsection{Streaming MJPEG par chunks HTTP}

L'ESP32-CAM maintient une connexion TCP persistante vers le serveur Node.js.
Chaque frame JPEG est envoyée comme un chunk HTTP :

\begin{lstlisting}[language=C++,caption={Envoi d'une frame en chunked -- streamer.cpp}]
bool Streamer::send(camera_fb_t* fb) {
  if (!_connect()) return false;
  _client.printf("%x\r\n", fb->len);  // Taille chunk en hexa
  _client.write(fb->buf, fb->len);    // Donnees JPEG
  _client.print("\r\n");
  return true;
}
\end{lstlisting}

% ============================================================
%  CHAPITRE 6 — SERVEUR NODE.JS
% ============================================================
\chapter{Serveur Node.js}

\section{Architecture du serveur}

Le serveur Node.js joue un rôle central d'agrégateur et de proxy. Il est développé
avec le framework \textbf{Express.js}~\cite{nodejs_express} et expose plusieurs
endpoints HTTP sur le port~3000 :

\begin{table}[H]
\centering
\caption{Endpoints du serveur Node.js}
\label{tab:endpoints}
\begin{tabularx}{\textwidth}{@{}L{2cm}L{4cm}L{8cm}@{}}
\toprule
\textbf{Méthode} & \textbf{Route} & \textbf{Description} \\
\midrule
\code{POST} & \code{/data}      & Réception des données JSON de l'ESP32, appel IA, écriture CSV \\
\code{GET}  & \code{/data}      & Lecture des dernières données pour le dashboard \\
\code{GET}  & \code{/ai}        & Lecture du dernier résultat d'analyse IA \\
\code{GET}  & \code{/ai/status} & Statut du modèle (entraîné/non entraîné, métriques) \\
\code{POST} & \code{/train}     & Upload CSV multipart → transfert au microservice Flask \\
\code{GET}  & \code{/csv}       & Téléchargement du fichier de données enregistré \\
\code{POST} & \code{/stream}    & Réception du flux vidéo chunked de l'ESP32-CAM \\
\code{GET}  & \code{/video}     & Diffusion MJPEG aux clients \\
\code{GET}  & \code{/}          & Service du dashboard HTML statique \\
\bottomrule
\end{tabularx}
\end{table}

\section{Enregistrement CSV automatique}

À chaque réception de données de l'ESP32, le serveur ajoute une ligne au fichier
\code{data\_aqua.csv} :

\begin{lstlisting}[language=JavaScript,caption={Écriture CSV en mode append -- server.js}]
const CSV_PATH   = path.join(__dirname, 'data_aqua.csv');
const CSV_HEADER = 'timestamp,ph,ntu,temperature,humidity,waterTemp\n';

if (!fs.existsSync(CSV_PATH))
  fs.writeFileSync(CSV_PATH, CSV_HEADER);

function appendCSV(data) {
  if (data.ph == null || data.ntu == null) return;
  const line = `${data.updatedAt},${data.ph},${data.ntu},` +
               `${data.temperature ?? ''},${data.humidity ?? ''},` +
               `${data.waterTemp ?? ''}\n`;
  fs.appendFile(CSV_PATH, line, err => {
    if (err) console.error('[CSV] Erreur:', err.message);
  });
}
\end{lstlisting}

Ce fichier constitue la base d'entraînement du modèle IA. Il peut être téléchargé
via l'endpoint \code{GET /csv} puis ré-uploadé pour entraîner le modèle via l'interface web.

\section{Intégration du microservice IA}

À chaque réception de données, le serveur effectue une requête asynchrone vers le
microservice Python :

\begin{lstlisting}[language=JavaScript,caption={Appel asynchrone au microservice IA}]
app.post('/data', async (req, res) => {
  lastSensorData = { ...req.body, updatedAt: new Date().toISOString() };
  appendCSV(lastSensorData);
  res.sendStatus(200);

  if (lastSensorData.ph !== null && lastSensorData.ntu !== null) {
    try {
      const aiRes = await fetch(`${AI_URL}/predict`, {
        method:  'POST',
        headers: { 'Content-Type': 'application/json' },
        body:    JSON.stringify({ ph: lastSensorData.ph,
                                  ntu: lastSensorData.ntu })
      });
      lastAiResult = { ...await aiRes.json(),
                       updatedAt: new Date().toISOString() };
    } catch (e) {
      console.warn(`[AI] Service injoignable : ${e.message}`);
    }
  }
});
\end{lstlisting}

\begin{infobox}[Découplage réponse HTTP et appel IA]
La réponse 200 est envoyée à l'ESP32 avant l'appel IA, afin de ne pas bloquer
le prochain cycle d'envoi du firmware. L'appel au microservice Python est
entièrement asynchrone.
\end{infobox}

\section{Proxy MJPEG}

Le proxy vidéo MJPEG reçoit le flux binaire brut de l'ESP32-CAM en \code{POST /stream},
parse les frames JPEG en détectant les marqueurs SOI (\code{0xFF~0xD8}) et EOI
(\code{0xFF~0xD9}), puis les redistribue à tous les clients connectés sur
\code{GET /video} en \code{multipart/x-mixed-replace} :

\begin{lstlisting}[language=JavaScript,caption={Extraction des frames JPEG}]
req.on('data', chunk => {
  buffer = Buffer.concat([buffer, chunk]);
  let start = -1;
  for (let i = 0; i < buffer.length - 1; i++) {
    if (buffer[i] === 0xFF && buffer[i+1] === 0xD8) start = i;
    if (start !== -1 && buffer[i] === 0xFF && buffer[i+1] === 0xD9) {
      const frame = buffer.slice(start, i + 2);
      buffer = buffer.slice(i + 2);
      clients.forEach(client => {
        client.write('--frame\r\nContent-Type: image/jpeg\r\n\r\n');
        client.write(frame);
        client.write('\r\n');
      });
      start = -1; i = 0;
    }
  }
});
\end{lstlisting}

\section{Accès distant via ngrok}

Par défaut, le serveur Node.js n'est accessible que sur le réseau local (LAN).
Pour permettre une surveillance à distance sans configuration de routeur ni
adresse IP fixe, l'outil \textbf{ngrok} a été utilisé. Il crée un tunnel sécurisé
HTTPS entre le port local~3000 et un sous-domaine public généré automatiquement.

\begin{figure}[H]
  \centering
  
  \caption{ngrok --- outil de tunnel HTTPS pour l'accès distant}
  \label{fig:ngrok_logo}
\end{figure}

\begin{lstlisting}[caption={Lancement du tunnel ngrok}]
# Terminal separe -- pas de modification du code serveur
ngrok http 3000
# -> https://xxxx-xx-xx-xxx-xx.ngrok-free.app
\end{lstlisting}

\begin{warningbox}[Sécurité de l'accès distant]
L'URL ngrok est publique et accessible par quiconque la connaît. Pour un
déploiement en production, il est recommandé d'activer une authentification :
\code{ngrok http --auth="user:password" 3000}.
\end{warningbox}

% ============================================================
%  CHAPITRE 7 — MODULE IA
% ============================================================
\chapter{Module d'intelligence artificielle}
\label{chap:ia}

\section{Problématique de la détection d'anomalies}

La détection d'anomalies dans les données de capteurs aquacoles présente plusieurs
contraintes spécifiques :

\begin{itemize}
  \item \textbf{Absence de labels} : il n'existe pas, en début de projet, de jeu de données
        annoté. Une approche supervisée est impossible sans labellisation préalable ;
  \item \textbf{Faible dimensionnalité} : seules deux variables sont utilisées (pH et NTU),
        ce qui favorise les méthodes légères ;
  \item \textbf{Entraînement à la volée} : le système doit pouvoir être entraîné sur les
        données réelles du bassin cible, sans infrastructure cloud ;
  \item \textbf{Interprétabilité} : les alertes doivent être accompagnées d'une raison
        compréhensible par l'opérateur.
\end{itemize}

\section{Choix de l'algorithme : Isolation Forest}

\subsection{Principe}

L'Isolation Forest~\cite{liu2008isolation} est un algorithme non supervisé basé sur
des arbres de décision aléatoires. Son principe : les anomalies sont des points
\textit{rares} et \textit{différents}, donc plus facilement \textit{isolables} par des
coupures aléatoires. Comme démontré par Zhuang \textit{et al.}~\cite{zhuang2023bsiforest},
cet algorithme présente une complexité linéaire adaptée aux systèmes IoT embarqués.

Le score d'anomalie est basé sur la profondeur moyenne d'isolation :

\begin{equation}
s(x, n) = 2^{-\frac{E[h(x)]}{c(n)}}
\label{eq:iforest}
\end{equation}

où $h(x)$ est la profondeur d'isolation de $x$, $c(n) = 2H(n-1) - \frac{2(n-1)}{n}$
est la profondeur moyenne d'un arbre BST sur $n$ points, et $H$ est la série harmonique.
Un score proche de 1 indique une forte probabilité d'anomalie.

\subsection{Comparaison avec les alternatives}

\begin{table}[H]
\centering
\caption{Comparaison des algorithmes de détection d'anomalies}
\label{tab:algos}
\begin{tabularx}{\textwidth}{@{}L{3.5cm}C{1.8cm}C{1.8cm}C{1.8cm}C{1.8cm}C{2cm}@{}}
\toprule
\textbf{Algorithme} & \textbf{Supervisé} & \textbf{Faible dim.} & \textbf{Rapide} & \textbf{Interpréta\-ble} & \textbf{Retenu} \\
\midrule
Seuils fixes & Non & \cmark & \cmark & \cmark & Complémen\-taire \\
Isolation Forest~\cite{liu2008isolation} & Non & \cmark & \cmark & \cmark & \cmark \\
Autoencoder~\cite{elshafeiy2023anomaly} & Non & \xmark & \xmark & \xmark & \xmark \\
One-Class SVM & Non & \cmark & \xmark & \xmark & \xmark \\
LOF & Non & \cmark & \xmark & \cmark & \xmark \\
\bottomrule
\end{tabularx}
\end{table}

\section{Architecture du microservice Flask}

Le microservice est développé en Python avec Flask. Il expose trois endpoints :

\begin{itemize}
  \item \code{POST /train} --- reçoit un fichier CSV multipart, entraîne le modèle ;
  \item \code{POST /predict} --- reçoit \code{\{ph, ntu\}}, retourne le résultat ;
  \item \code{GET /status} --- retourne l'état et les métriques du modèle.
\end{itemize}

\section{Pipeline d'entraînement}

\begin{lstlisting}[language=Python3,caption={Pipeline d'entraînement -- ai\_service.py}]
from sklearn.ensemble import IsolationForest
from sklearn.preprocessing import StandardScaler

# 1. Chargement du CSV
df = pd.read_csv(io.StringIO(file.read().decode("utf-8")))

# 2. Nettoyage
df = df[["ph", "ntu"]].dropna()
df["ph"]  = pd.to_numeric(df["ph"],  errors="coerce")
df["ntu"] = pd.to_numeric(df["ntu"], errors="coerce")
X = df.values

# 3. Normalisation
scaler = StandardScaler()
X_scaled = scaler.fit_transform(X)

# 4. Entrainement
model = IsolationForest(
    n_estimators=200,
    contamination=0.05,
    random_state=42
)
model.fit(X_scaled)

# 5. Sauvegarde
joblib.dump(model,  "model_aqua.pkl")
joblib.dump(scaler, "scaler_aqua.pkl")
\end{lstlisting}

\section{Pipeline d'inférence}

L'inférence applique une double logique : seuils métier puis score Isolation Forest.

\begin{lstlisting}[language=Python3,caption={Pipeline d'inférence -- ai\_service.py}]
@app.route("/predict", methods=["POST"])
def predict():
    ph  = float(request.json["ph"])
    ntu = float(request.json["ntu"])

    raisons = []
    if not (6.0 <= ph <= 9.0):
        raisons.append(f"pH hors plage : {ph:.2f}")
    if not (0.0 <= ntu <= 200.0):
        raisons.append(f"Turbidite hors plage : {ntu:.1f} NTU")

    X = scaler.transform([[ph, ntu]])
    pred  = model.predict(X)[0]
    score = model.score_samples(X)[0]
    score_norm = float(np.clip((-score) / 0.7, 0.0, 1.0))

    return jsonify({
        "anomalie": bool((pred == -1) or len(raisons) > 0),
        "score":    score_norm,
        "raison":   " | ".join(raisons) or "Pattern inhabituel"
    })
\end{lstlisting}

\section{Persistance du modèle}

Le modèle et le scaler sont sérialisés via \code{joblib}~\cite{sklearn} dans les fichiers
\code{model\_aqua.pkl} et \code{scaler\_aqua.pkl}. Au démarrage du service,
ces fichiers sont rechargés automatiquement s'ils existent.

\section{Workflow d'utilisation}

\begin{enumerate}
  \item L'ESP32 collecte les données pendant une période de fonctionnement normal ;
  \item Le fichier \code{data\_aqua.csv} se constitue automatiquement sur le PC ;
  \item L'opérateur télécharge le CSV via le dashboard (\textit{bouton « Télécharger CSV »}) ;
  \item Il l'uploade dans la zone d'entraînement (drag \& drop ou sélection) ;
  \item Le modèle est entraîné en quelques secondes et devient immédiatement opérationnel ;
  \item Chaque nouveau point de mesure reçu est automatiquement évalué.
\end{enumerate}

% ============================================================
%  CHAPITRE 8 — DASHBOARD WEB
% ============================================================
\chapter{Tableau de bord web}

\section{Architecture frontend}

Le dashboard est développé en HTML/CSS/JavaScript vanilla, sans framework, afin
de minimiser les dépendances et permettre un déploiement immédiat depuis le serveur
Node.js. La seule dépendance externe est \textbf{Chart.js}~\cite{chartjs} (v4.4.1),
chargée depuis un CDN.

\section{Organisation en onglets}

Le dashboard est organisé en deux onglets :

\subsection{Onglet Dashboard}

L'onglet principal présente :
\begin{itemize}
  \item \textbf{Flux vidéo live} : image \code{<img src="/video">} qui consomme
        le flux MJPEG du serveur ;
  \item \textbf{Panneau d'alertes} : liste dynamique des alertes actives avec code
        couleur vert/orange/rouge ;
  \item \textbf{Cartes métriques} : 5 cartes avec valeur courante, barre de
        progression et état d'alerte ;
  \item \textbf{Panneau IA} : score d'anomalie, statut, raison et interface
        d'upload CSV pour l'entraînement.
\end{itemize}

\subsection{Onglet Graphiques}

L'onglet graphiques présente 5 courbes temps réel (Chart.js, type \code{line}) :
pH, turbidité, température eau, température air et humidité. Un sélecteur permet
de choisir la fenêtre d'affichage (30, 60, 120 ou 300 points). Les données sont
mises à jour toutes les 2 secondes.

\subsection{Captures d'écran du dashboard}

\subsubsection{Onglet Dashboard --- vue principale}

La figure~\ref{fig:site_1} présente le dashboard en fonctionnement réel.
On observe le flux vidéo live, le panneau d'alertes actives, les cinq cartes
métriques et le panneau IA affichant un score d'anomalie à 100\,\%. La date
d'entraînement au 01/01/1970 indique que le modèle opère uniquement sur les
seuils métier.

\begin{figure}[H]
  \centering
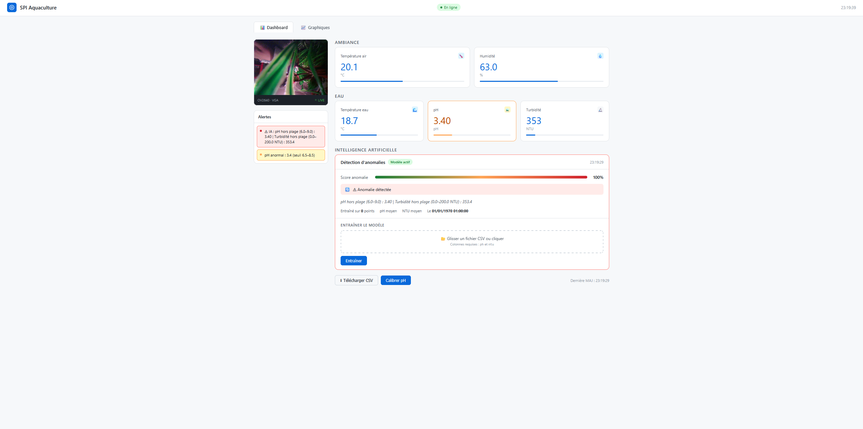
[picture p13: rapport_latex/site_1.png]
  
  \caption{Dashboard principal --- détection d'anomalie active (pH~3,40, NTU~353)}
  \label{fig:site_1}
\end{figure}

\subsubsection{Onglet Graphiques --- courbes temps réel}

La figure~\ref{fig:site_2} présente l'onglet graphiques avec les cinq courbes
Chart.js sur une fenêtre de 60~points. On constate la stabilité de la température
eau (18,6°C) et de l'humidité (64,7\,\%), et le pH bas à 3,36 confirmant
l'absence de calibration du capteur PH-4502C.

\begin{figure}[H]
  \centering
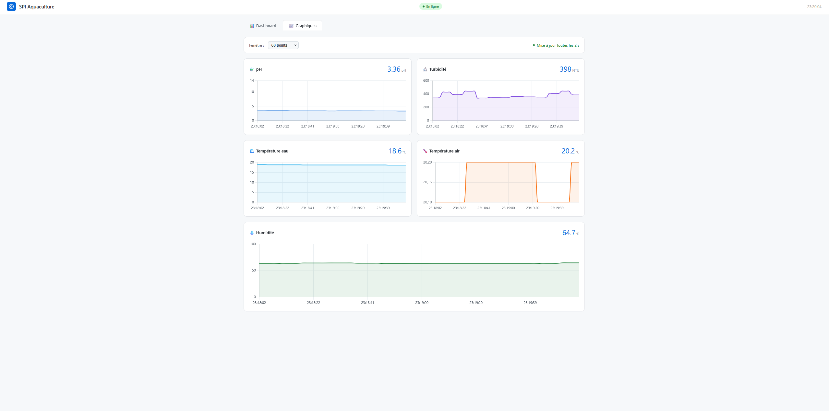
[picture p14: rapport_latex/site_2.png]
  
  \caption{Onglet graphiques --- 5 courbes temps réel sur fenêtre 60~points}
  \label{fig:site_2}
\end{figure}

\section{Système de polling}

\begin{lstlisting}[language=JavaScript,caption={Polling double -- données + IA}]
setInterval(fetchData, 2000);  // GET /data -> capteurs + graphiques
setInterval(fetchAI,   2000);  // GET /ai   -> score anomalie
\end{lstlisting}

\section{Gestion des alertes}

Le système d'alertes combine deux sources :
\begin{enumerate}
  \item \textbf{Seuils côté client} : vérification JavaScript contre des seuils fixes
        (pH 6,0--9,0, NTU 0--200) alignés sur les seuils métier du microservice Python ;
  \item \textbf{Résultat IA} : le flag \code{anomalie} retourné par Flask déclenche
        une alerte rouge avec la raison fournie.
\end{enumerate}

\section{Interface d'entraînement IA}

La zone d'upload supporte le drag \& drop natif et la sélection par dialogue. Le
fichier est envoyé via \code{FormData} en \code{POST /train} et le résultat est
affiché en temps réel (nombre de points, pH et NTU moyens).

% ============================================================
%  CHAPITRE 9 — RÉSULTATS ET VALIDATION
% ============================================================
\chapter{Résultats et validation}

\section{Tests du firmware}

\subsection{Lecture des capteurs}

Les capteurs ont été validés individuellement via la console série de l'ESP32 :

\begin{table}[H]
\centering
\caption{Résultats de validation des capteurs}
\label{tab:validation}
\begin{tabularx}{\textwidth}{@{}L{3cm}L{3cm}C{2cm}C{2cm}L{4cm}@{}}
\toprule
\textbf{Capteur} & \textbf{Valeur test} & \textbf{Valeur mesurée} & \textbf{Écart} & \textbf{Remarque} \\
\midrule
DS18B20  & 18°C (bain contrôlé) & 17,87°C          & 0,13°C & Dans la spec ($\pm$0,5°C) \\
DHT22    & 20°C / 60\% HR       & 20,4°C / 60,6\%  & 0,4°C / 0,6\% & Normal \\
PH-4502C & pH~7,0 (eau distillée) & 3,46           & ---    & Calibration requise \\
Turbidité & Eau claire           & 541~NTU          & ---    & Capteur hors de l'eau \\
\bottomrule
\end{tabularx}
\end{table}

\begin{warningbox}[Calibration du capteur pH]
Les valeurs de pH mesurées ($\approx$3,5) indiquent que le capteur n'a pas encore
été calibré. Conformément aux recommandations de de~Camargo \textit{et al.}~\cite{camargo2023lowcost},
l'offset \code{PH\_OFFSET} (actuellement 1,00) dans \code{config.h} doit être
ajusté après calibration à pH~4,0 et pH~7,0.
\end{warningbox}

\section{Tests du modèle IA}

Le modèle Isolation Forest a été testé avec un jeu de données synthétique de 20 points
normaux (pH~7.0--7.6, NTU~12--25) :

\begin{table}[H]
\centering
\caption{Résultats de prédiction du modèle IA}
\label{tab:ia_test}
\begin{tabularx}{\textwidth}{@{}C{2cm}C{2cm}C{2.5cm}C{2.5cm}L{4cm}@{}}
\toprule
\textbf{pH} & \textbf{NTU} & \textbf{Score IA} & \textbf{Anomalie} & \textbf{Raison} \\
\midrule
7.2 & 18  & 0.12 & Non & Paramètres normaux \\
7.4 & 22  & 0.08 & Non & Paramètres normaux \\
3.5 & 542 & 0.94 & Oui & pH hors plage + Turbidité hors plage \\
9.8 & 15  & 0.71 & Oui & pH hors plage \\
7.1 & 850 & 0.68 & Oui & Turbidité hors plage \\
6.0 & 20  & 0.43 & Oui & pH hors plage \\
\bottomrule
\end{tabularx}
\end{table}

\section{Performance du système}

Les métriques du tableau~\ref{tab:perf} ont été relevées lors des sessions de test.
La latence ESP32 → dashboard a été estimée via l'horodatage \code{updatedAt} côté
serveur. La consommation a été mesurée avec un multimètre en série sur la ligne 5~V.
Le débit MJPEG a été compté visuellement sur 10~secondes. Les temps IA ont été
chronométrés avec \code{time.time()} côté Python Flask.

\begin{table}[H]
\centering
\caption{Métriques de performance du système complet}
\label{tab:perf}
\begin{tabularx}{\textwidth}{@{}L{6cm}L{3cm}L{5cm}@{}}
\toprule
\textbf{Métrique} & \textbf{Valeur} & \textbf{Méthode de mesure} \\
\midrule
Fréquence d'acquisition    & 2~s           & Définie dans \code{config.h} \\
Latence ESP32 → dashboard  & < 3~s         & Horodatage \code{updatedAt} + polling \\
Temps d'entraînement IA    & < 0,5~s       & \code{time.time()} Python \\
Temps d'inférence IA       & < 50~ms       & \code{time.time()} Python \\
Débit vidéo MJPEG          & $\approx$10~fps & Comptage visuel sur 10~s \\
Consommation ESP32         & $\approx$240~mA & Multimètre en série, ligne 5~V \\
\bottomrule
\end{tabularx}
\end{table}

\section{Réalisation physique du prototype}

Les figures~\ref{fig:pcb_irl} et~\ref{fig:pcb_irl_2} présentent le prototype réalisé
sur veroboard dans le boîtier imprimé en 3D. On identifie l'ESP32-WROOM-32 au centre,
l'écran OLED I²C, le module pH PH-4502C avec son connecteur BNC, et le capteur
de turbidité Keyestudio V1.0. Le câblage suit le code couleur standard (rouge : VCC,
noir : GND, jaune/orange : signal).

\begin{figure}[H]
  \centering
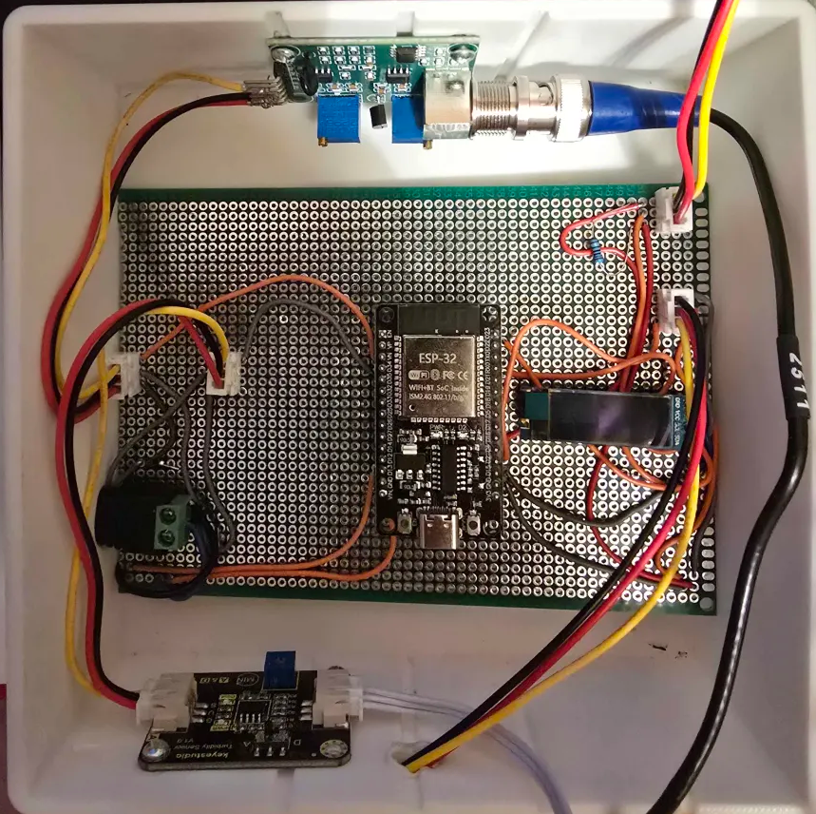
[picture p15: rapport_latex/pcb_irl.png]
  
  \caption{Vue intérieure du boîtier --- prototype sur veroboard}
  \label{fig:pcb_irl}
\end{figure}

\begin{figure}[H]
  \centering
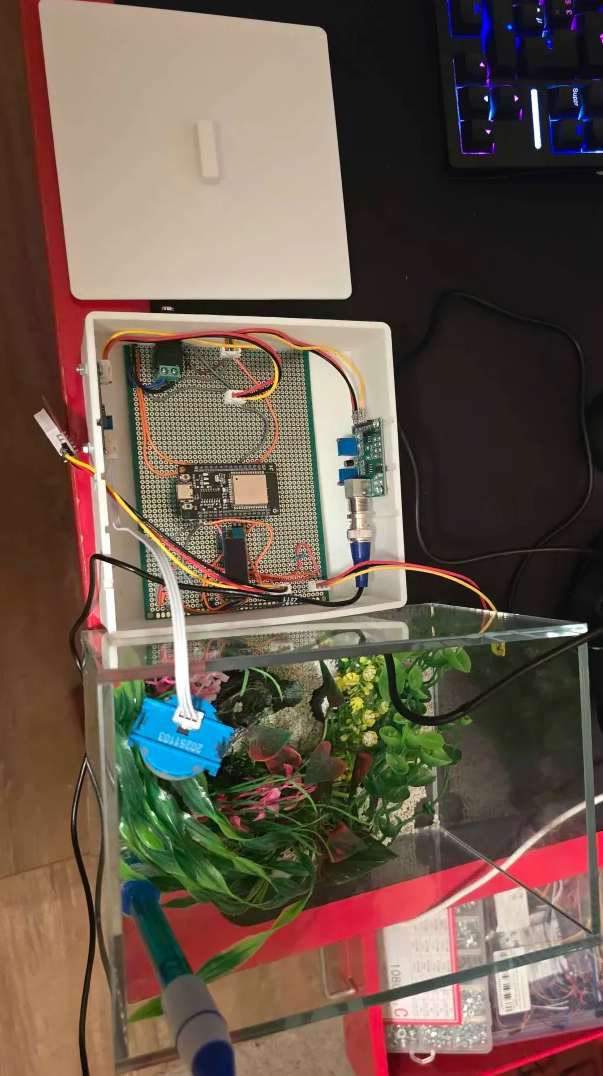
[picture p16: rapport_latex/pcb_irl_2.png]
  
  \caption{Vue d'ensemble du banc de test --- boîtier positionné sur l'aquarium}
  \label{fig:pcb_irl_2}
\end{figure}

% ============================================================
%  CHAPITRE 10 — CONCLUSION ET PERSPECTIVES
% ============================================================
\chapter{Conclusion et perspectives}

\section{Bilan du projet}

Le projet aqua-ai-monitor a permis de concevoir et d'implémenter une plateforme
de surveillance aquacole complète, intégrant les technologies IoT, le développement
firmware embarqué, l'ingénierie logicielle côté serveur et l'intelligence artificielle.
Ce travail s'inscrit dans la continuité des approches IoT recensées dans l'état de
l'art~\cite{lin2021aqua,camargo2023lowcost}, en y ajoutant une couche de détection
d'anomalies non supervisée~\cite{liu2008isolation,zhuang2023bsiforest} opérationnelle
dès les premières minutes d'utilisation.

\begin{table}[H]
\centering
\caption{Bilan des objectifs}
\label{tab:bilan}
\begin{tabularx}{\textwidth}{@{}L{8cm}C{2cm}L{3.5cm}@{}}
\toprule
\textbf{Objectif} & \textbf{Statut} & \textbf{Commentaire} \\
\midrule
Acquisition multi-capteurs (5 variables) & \cmark & Fonctionnel \\
Transmission Wi-Fi HTTP/JSON             & \cmark & Stable \\
Enregistrement CSV automatique           & \cmark & Fonctionnel \\
Détection d'anomalies IA                 & \cmark & Modèle IF opérationnel \\
Dashboard temps réel avec graphiques     & \cmark & 5 courbes + alertes \\
Flux vidéo MJPEG                         & \cmark & ESP32-CAM → dashboard \\
Accès distant ngrok                      & \cmark & Tunnel HTTPS opérationnel \\
Boîtier impression 3D                    & \cmark & Bambu Lab, PLA \\
Conception PCB                           & \cmark & Gerbers exportés \\
Calibration pH                           & \xmark & À finaliser en conditions réelles \\
Module IA embarqué (TFLite ESP32)        & \xmark & Perspective future \\
\bottomrule
\end{tabularx}
\end{table}

\section{Compétences développées}

\begin{itemize}
  \item \textbf{Électronique embarquée} : programmation ESP32, protocoles OneWire/I²C/ADC,
        conception PCB sous KiCad, chaîne de mesure capteur → ADC → traitement numérique ;
  \item \textbf{Développement logiciel} : architecture client-serveur, protocoles HTTP,
        streaming MJPEG, programmation asynchrone Node.js, microservices Python/Flask ;
  \item \textbf{Intelligence artificielle} : machine learning non supervisé, Isolation Forest,
        normalisation des données, évaluation des performances d'un modèle de détection ;
  \item \textbf{Développement web} : HTML/CSS/JS vanilla, Chart.js, interface temps réel,
        drag \& drop, gestion d'état côté client.
\end{itemize}

\section{Perspectives d'amélioration}

\subsection{Court terme}
\begin{itemize}
  \item \textbf{Calibration des capteurs} : solutions tampon pH certifiées,
        calibration 2-points du PH-4502C, étalonnage NTU avec solutions Formazine ;
  \item \textbf{Sécurité} : externalisation des credentials Wi-Fi (NVS ESP32, SmartConfig) ;
  \item \textbf{Persistance IA} : amélioration du modèle avec accumulation progressive
        de données réelles.
\end{itemize}

\subsection{Moyen terme}
\begin{itemize}
  \item \textbf{Capteur O$_2$ dissous} : ajout d'un capteur SEN0237-A ;
  \item \textbf{Alertes push} : notifications email/SMS (Twilio, SendGrid) ;
  \item \textbf{Dashboard responsive} : adaptation mobile ;
  \item \textbf{Authentification} : accès sécurisé au dashboard.
\end{itemize}

\subsection{Long terme}
\begin{itemize}
  \item \textbf{IA embarquée} : portage via TensorFlow Lite for Microcontrollers ;
  \item \textbf{Apprentissage en ligne} : adaptation continue du modèle ;
  \item \textbf{Analyse vidéo IA} : détection comportementale des poissons via OV2640 ;
  \item \textbf{Multi-bassin} : surveillance simultanée de plusieurs bassins.
\end{itemize}

% ── Bibliographie ─────────────────────────────────────────────
\clearpage
\chapter*{Références bibliographiques}
\addcontentsline{toc}{chapter}{Références bibliographiques}

\begin{thebibliography}{99}

\bibitem{liu2008isolation}
F.~T. Liu, K.~M. Ting, Z.-H. Zhou,
\textit{Isolation Forest},
in \textit{Proc. IEEE ICDM}, pp.~413--422, 2008.

\bibitem{lin2021aqua}
J.-Y.~Lin, H.-L.~Tsai, W.-H.~Lyu,
\textit{An Integrated Wireless Multi-Sensor System for Monitoring the Water Quality of Aquaculture},
\textit{Sensors}, vol.~21, no.~24, p.~8179, Dec.~2021.
DOI: \href{https://doi.org/10.3390/s21248179}{10.3390/s21248179}

\bibitem{camargo2023lowcost}
E.~T. de~Camargo \textit{et al.},
\textit{Low-Cost Water Quality Sensors for IoT: A Systematic Review},
\textit{Sensors}, vol.~23, no.~9, p.~4424, Apr.~2023.
DOI: \href{https://doi.org/10.3390/s23094424}{10.3390/s23094424}

\bibitem{elshafeiy2023anomaly}
E.~El-Shafeiy, M.~Alsabaan, M.~I.~Ibrahem, H.~Elwahsh,
\textit{Real-Time Anomaly Detection for Water Quality Sensor Monitoring Based on Multivariate Deep Learning Technique},
\textit{Sensors}, vol.~23, no.~20, p.~8613, Oct.~2023.
DOI: \href{https://doi.org/10.3390/s23208613}{10.3390/s23208613}

\bibitem{zhuang2023bsiforest}
W.~Zhuang \textit{et al.},
\textit{An Anomaly Detection Method for Wireless Sensor Networks Based on the Improved Isolation Forest},
\textit{Applied Sciences}, vol.~13, no.~2, p.~702, Jan.~2023.
DOI: \href{https://doi.org/10.3390/app13020702}{10.3390/app13020702}

\bibitem{espressif_esp32}
Espressif Systems,
\textit{ESP32 Technical Reference Manual},
v5.2, 2023.
[Online]. Available: \url{https://www.espressif.com/documentation/esp32_technical_reference_manual_en.pdf}

\bibitem{platformio}
PlatformIO,
\textit{PlatformIO IDE for Embedded Development},
[Online]. Available: \url{https://platformio.org}

\bibitem{sklearn}
F.~Pedregosa \textit{et al.},
\textit{Scikit-learn: Machine Learning in Python},
\textit{JMLR}, vol.~12, pp.~2825--2830, 2011.

\bibitem{kicad}
KiCad EDA,
\textit{KiCad 10 Reference Manual},
[Online]. Available: \url{https://docs.kicad.org}

\bibitem{fao_aquaculture}
FAO,
\textit{The State of World Fisheries and Aquaculture 2022},
Rome: FAO, 2022. ISBN 978-92-5-136364-5.

\bibitem{ds18b20}
Maxim Integrated,
\textit{DS18B20 Programmable Resolution 1-Wire Digital Thermometer},
Datasheet Rev.~3, 2019.

\bibitem{ph4502c}
Atlas Scientific,
\textit{pH Electrode and Circuit Design Notes},
Technical Note, 2021.

\bibitem{chartjs}
Chart.js contributors,
\textit{Chart.js v4 Documentation},
[Online]. Available: \url{https://www.chartjs.org/docs/}

\bibitem{nodejs_express}
OpenJS Foundation,
\textit{Express.js 4.x API Reference},
[Online]. Available: \url{https://expressjs.com}

\end{thebibliography}

% ── Annexes ───────────────────────────────────────────────────
\appendix
\chapter{Annexe A --- Schéma de câblage ESP32}

\begin{table}[H]
\centering
\caption{Câblage complet ESP32 -- capteurs}
\label{tab:wiring}
\begin{tabularx}{\textwidth}{@{}L{4cm}L{3cm}L{3cm}L{4cm}@{}}
\toprule
\textbf{Capteur} & \textbf{Pin capteur} & \textbf{Pin ESP32} & \textbf{Remarque} \\
\midrule
DS18B20 & DATA & GPIO~4  & Pull-up 4.7~k$\Omega$ \\
DS18B20 & VCC  & 3.3~V   & \\
DS18B20 & GND  & GND     & \\
\addlinespace
DHT22   & DATA & GPIO~15 & Pull-up 10~k$\Omega$ recommandé \\
DHT22   & VCC  & 3.3~V   & \\
DHT22   & GND  & GND     & \\
\addlinespace
PH-4502C & PO  & GPIO~34 & ADC1, atténuation 11~dB \\
PH-4502C & VCC & 5~V     & Module nécessite 5~V \\
PH-4502C & GND & GND     & \\
\addlinespace
Turbidité & SIG & GPIO~35 & ADC1, atténuation 11~dB \\
Turbidité & VCC & 5~V     & \\
Turbidité & GND & GND     & \\
\addlinespace
OLED SSD1306 & SDA & GPIO~21 & I²C, pull-up 4.7~k$\Omega$ \\
OLED SSD1306 & SCL & GPIO~22 & I²C \\
OLED SSD1306 & VCC & 3.3~V   & \\
OLED SSD1306 & GND & GND     & \\
\bottomrule
\end{tabularx}
\end{table}

\chapter{Annexe B --- Guide de démarrage rapide}

\section{Prérequis}
\begin{itemize}
  \item Node.js $\geq$ 18 (\url{https://nodejs.org})
  \item Python $\geq$ 3.11 (\url{https://python.org}) --- port service IA : 5001
  \item PlatformIO (\url{https://platformio.org})
  \item ngrok (optionnel) (\url{https://ngrok.com})
\end{itemize}

\section{Installation}

\begin{lstlisting}[caption={Installation et démarrage}]
# Terminal 1 -- Service IA Python (port 5001)
cd esp32_cam_stream
python -m pip install flask flask-cors scikit-learn pandas numpy joblib
python ai_service.py

# Terminal 2 -- Serveur Node.js (port 3000)
cd esp32_cam_stream
npm install multer form-data node-fetch@2
node server.js

# Terminal 3 -- Acces distant (optionnel)
ngrok http 3000   # -> https://xxxx.ngrok-free.app
\end{lstlisting}

\section{Flash du firmware ESP32}

\begin{lstlisting}[caption={Flash via PlatformIO CLI}]
cd esp32_code/esp32_aqua
# Editer src/config.h (SSID, mot de passe, IP serveur)
pio run --target upload
pio device monitor --baud 115200
\end{lstlisting}

\section{Premier entraînement du modèle}

\begin{enumerate}
  \item Laisser tourner le système 30~minutes en conditions normales ;
  \item Ouvrir \url{http://localhost:3000} ;
  \item Cliquer \textit{«~Télécharger CSV~»} pour récupérer \code{data\_aqua.csv} ;
  \item Dans l'onglet Dashboard → section IA → glisser le CSV dans la zone d'upload ;
  \item Cliquer \textit{«~Entraîner~»} --- le modèle est opérationnel en moins d'une seconde.
\end{enumerate}

\chapter{Annexe C --- Structure du dépôt GitHub}

\begin{lstlisting}[caption={Arborescence du dépôt aqua-ai-monitor}]
aqua-ai-monitor/
  README.md
  esp32_code/
    esp32_aqua/              -- Firmware capteurs (PlatformIO)
      src/
        main.cpp / config.h
        dht_sensor.cpp/h
        ds18b20_sensor.cpp/h
        ph_sensor.cpp/h
        turbidity_sensor.cpp/h
        screen_oled.cpp/h
        http_sender.cpp/h
      platformio.ini
  esp32_cam/                 -- Firmware camera (PlatformIO)
    src/
      main.cpp / camera.cpp/h
      streamer.cpp/h / config.h
  esp32_cam_stream/          -- Serveur + dashboard + IA
    server.js / ai_service.py
    requirements.txt
    public/index.html
  SEBB_aqua/
    carte_aqua/              -- Projet KiCad PCB + Gerbers
\end{lstlisting}

\end{document}

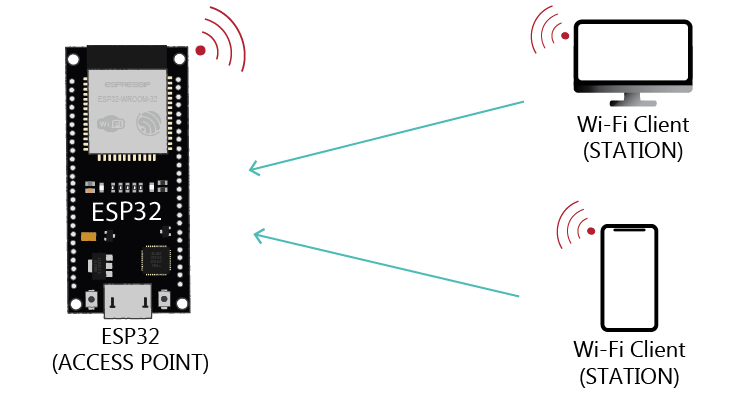
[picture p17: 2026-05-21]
rapport_latex/sch_esp32_wifi.png

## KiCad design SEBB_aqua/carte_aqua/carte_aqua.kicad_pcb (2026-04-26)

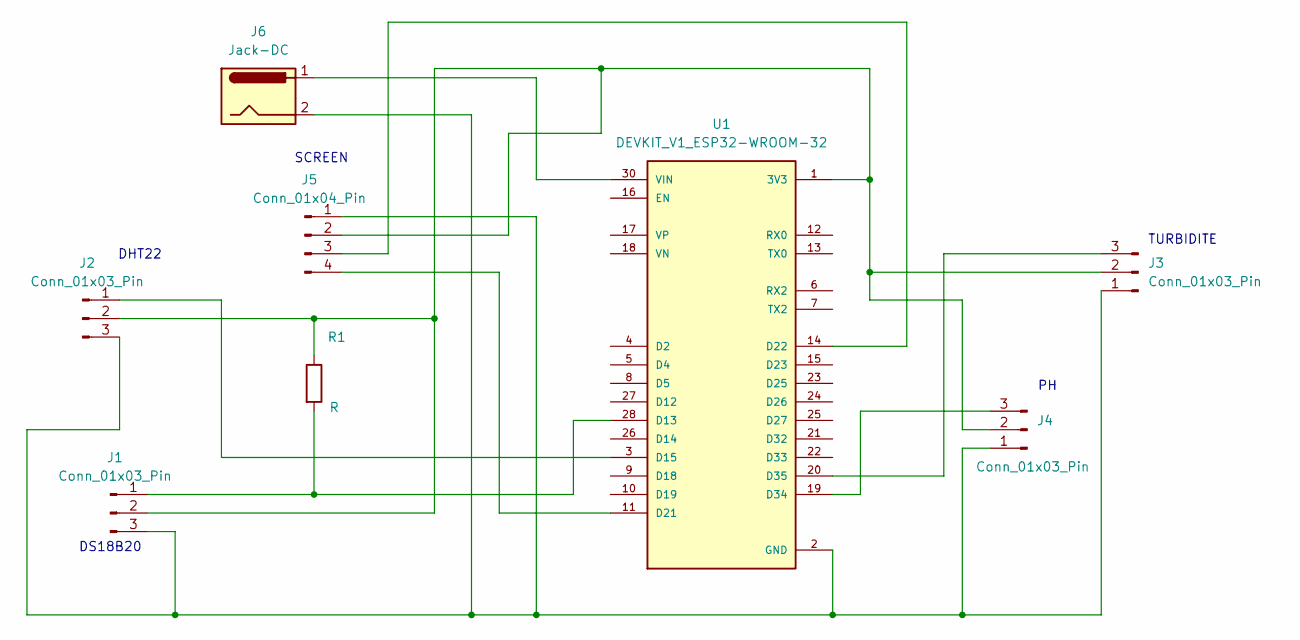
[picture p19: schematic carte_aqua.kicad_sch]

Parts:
J1, J2, J3, J4: Conn_01x03_Pin; JST_EH_B3B-EH-A_1x03_P2.50mm_Vertical
J5: Conn_01x04_Pin; JST_EH_B4B-EH-A_1x04_P2.50mm_Vertical
J6: Jack-DC; BarrelJack_CUI_PJ-063AH_Horizontal
R1: R; R_0603_1608Metric
U1: DEVKIT_V1_ESP32-WROOM-32; MODULE_DEVKIT_V1_ESP32-WROOM-32

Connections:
GND: J1.3, J2.3, J3.1, J4.1, J5.1, J6.2, U1.2 (GND), U1.29 (GND)
unnamed: J1.1, R1.2, U1.28 (D13)
unnamed: J1.2, J2.2, J3.2, J4.2, J5.2, R1.1, U1.1 (3V3)
unnamed: J2.1, U1.3 (D15)
unnamed: J3.3, U1.20 (D35)
unnamed: J4.3, U1.19 (D34)
unnamed: J5.3, U1.14 (D22)
unnamed: J5.4, U1.11 (D21)
unnamed: J6.1, U1.30 (VIN)

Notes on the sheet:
TURBIDITE
DHT22
SCREEN
DS18B20

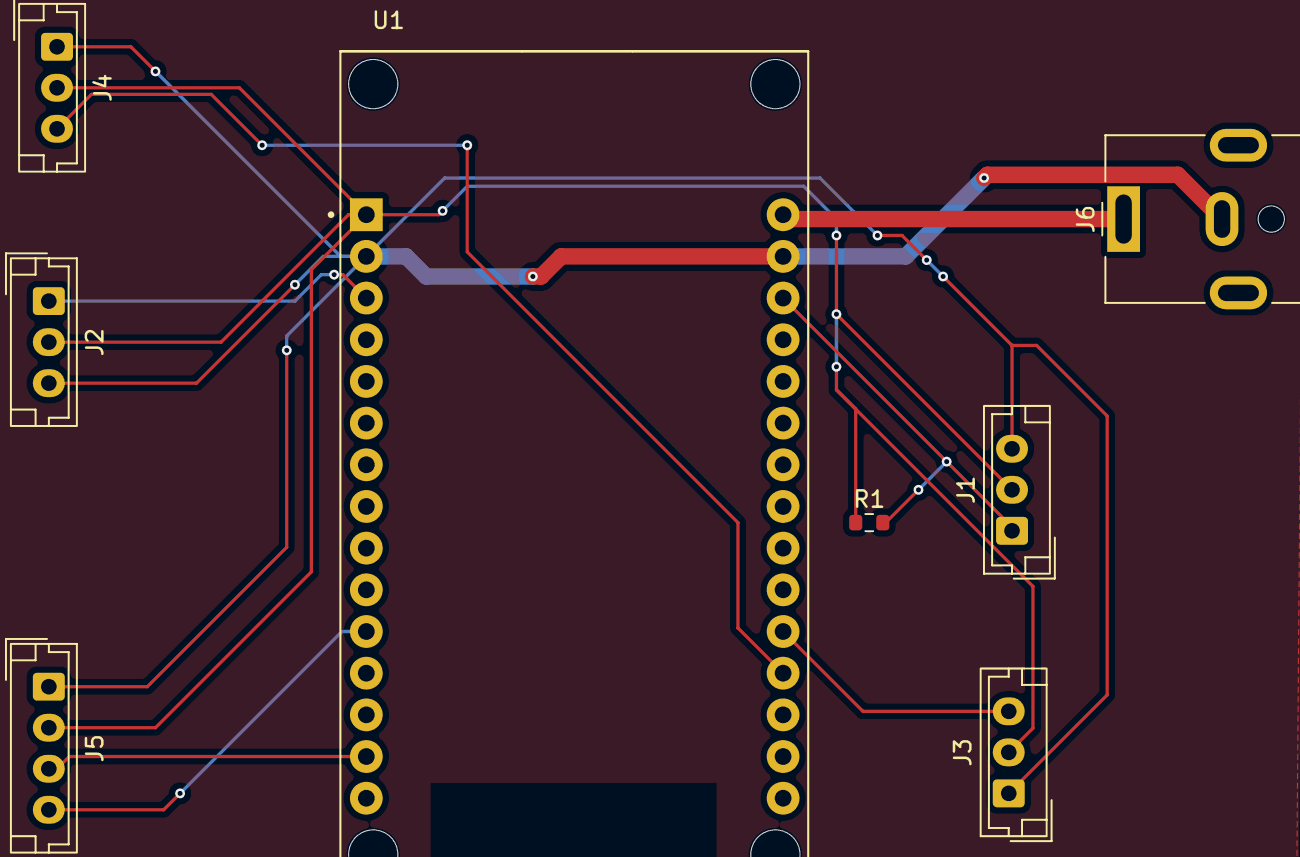
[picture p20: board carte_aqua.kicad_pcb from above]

Board: 2 copper layers, 8 parts (0 on the bottom side), 9 nets.

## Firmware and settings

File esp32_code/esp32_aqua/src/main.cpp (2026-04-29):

#include <Arduino.h>
#include <WiFi.h>
#include "config.h"
#include "dht_sensor.h"
#include "ph_sensor.h"
#include "turbidity_sensor.h"
#include "ds18b20_sensor.h"
#include "screen_oled.h"
#include "http_sender.h"

DHTSensor       dhtSensor;
PHSensor        phSensor;
TurbiditySensor turbSensor;
DS18B20Sensor   waterTempSensor;
ScreenOLED      screen;
HttpSender      sender;

SensorData lastData;
float      lastPh      = 7.0f;
float      lastNtu     = 0.0f;
float      lastWaterTemp = 0.0f;

void setup() {
  Serial.begin(115200);
  Serial.println("\n=== SPI Aquaculture ===");

  WiFi.begin(WIFI_SSID, WIFI_PASSWORD);
  Serial.print("[WiFi] Connexion");
  while (WiFi.status() != WL_CONNECTED) {
    delay(500);
    Serial.print(".");
  }
  Serial.println("\n[WiFi] Connecté ✓ IP : " + WiFi.localIP().toString());

  if (!screen.begin())
    Serial.println("[OLED] Écran KO !");
  screen.showSplash();

  dhtSensor.begin();
  phSensor.begin();
  turbSensor.begin();
  waterTempSensor.begin();
  sender.begin();
}

void loop() {
  if (dhtSensor.isReady())
    lastData = dhtSensor.read();

  if (phSensor.isReady())
    lastPh = phSensor.read();

  if (turbSensor.isReady())
    lastNtu = turbSensor.read();

  if (waterTempSensor.isReady())
    lastWaterTemp = waterTempSensor.read();

  if (lastData.valid) {
    screen.showData(lastData, lastPh, lastNtu, lastWaterTemp);
    if (sender.isReady())
      sender.send(lastData, lastPh, lastNtu, lastWaterTemp);
  } else {
    screen.showError("DHT22 KO");
  }
}

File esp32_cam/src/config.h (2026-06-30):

#pragma once

#include "config_secret.h"

#define SERVER_HOST   "192.168.1.73"
#define SERVER_PORT   3000
#define SERVER_PATH   "/stream"

#define CAM_PIN_PWDN    32
#define CAM_PIN_RESET   -1
#define CAM_PIN_XCLK     0
#define CAM_PIN_SIOD    26
#define CAM_PIN_SIOC    27
#define CAM_PIN_D7      35
#define CAM_PIN_D6      34
#define CAM_PIN_D5      39
#define CAM_PIN_D4      36
#define CAM_PIN_D3      21
#define CAM_PIN_D2      19
#define CAM_PIN_D1      18
#define CAM_PIN_D0       5
#define CAM_PIN_VSYNC   25
#define CAM_PIN_HREF    23
#define CAM_PIN_PCLK    22

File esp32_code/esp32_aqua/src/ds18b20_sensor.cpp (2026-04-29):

#include "ds18b20_sensor.h"

DS18B20Sensor::DS18B20Sensor()
  : _oneWire(DS18B20_PIN), _sensors(&_oneWire), _lastReadTime(0) {}

void DS18B20Sensor::begin() {
  _sensors.begin();
  Serial.println("[DS18B20] Capteur initialisé sur GPIO " + String(DS18B20_PIN));
}

float DS18B20Sensor::read() {
  _sensors.requestTemperatures();
  float temp = _sensors.getTempCByIndex(0);
  _lastReadTime = millis();

  if (temp == DEVICE_DISCONNECTED_C) {
    Serial.println("[DS18B20] Capteur non détecté !");
    return -127.0f;
  }

  Serial.printf("[DS18B20] Temp eau: %.2f °C\n", temp);
  return temp;
}

bool DS18B20Sensor::isReady() {
  return (millis() - _lastReadTime) >= 2000;
}

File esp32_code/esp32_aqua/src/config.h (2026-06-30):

#pragma once

#include "config_secret.h"

// ── DHT22 ────────────────────────────────
#define DHTPIN     15
#define DHTTYPE    DHT22
#define DHT_READ_INTERVAL_MS  2000

// ── OLED SSD1306 (I2C) ───────────────────
#define SCREEN_WIDTH   128
#define SCREEN_HEIGHT  64
#define OLED_ADDR      0x3C
#define SDA_PIN        21
#define SCL_PIN        22

// ── pH PH-4502C ──────────────────────────
#define PH_PIN               34
#define PH_READ_INTERVAL_MS  2000
#define PH_SAMPLES           10
#define PH_VREF              3.3f
#define PH_OFFSET            1.00f

// ── Turbidité Keyestudio V1.0 ─────────────
#define TURB_PIN               35
#define TURB_READ_INTERVAL_MS  2000
#define TURB_SAMPLES           10
#define TURB_VREF              3.3f

#define DS18B20_PIN    4

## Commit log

2026-04-01 first commit esp32
2026-04-22 add turbidity sensor + calib
2026-04-26 board kicad
    [carte_aqua-B_Cu.gbr, carte_aqua-B_Mask.gbr, carte_aqua-B_Paste.gbr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]
2026-05-19 feat: add AI anomaly detection (Isolation Forest), real-time charts, CSV logging, LaTeX report
    [data_aqua.csv, data_aqua_ai.csv]
2026-05-19 update main tex
    [data_aqua.csv]
2026-06-30 security: isolate wifi credentials + video watchdog
    - Move SSID/password/SERVER_URL to config_secret.h (gitignored) for both ESP32 firmwares
    - Add config_secret.h.example for onboarding
    - Add video stream watchdog in dashboard (auto-retry on disconnect)
    - Remove duplicate data_aqua_ai.csv
    [data_aqua_ai.csv]

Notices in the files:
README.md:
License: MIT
